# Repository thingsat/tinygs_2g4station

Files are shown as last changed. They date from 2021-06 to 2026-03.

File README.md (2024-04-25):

# TinyGS :: 2.4 GHz LoRa (low cost and low tech) ground station

Project to develop a ground station board that will receive messages from satellite on the 2.4GHz band. Satellite tracks are [Thingsat@STORK1](https://tinygs.com/satellite/ThingSat) and other cubeseat followed by the TinyGS community. This station is low cost (off the shelves boards and modules) and low tech (required only a solder iron).

This Git contains Hardware and software of a TinyGS 2.4 GHz LoRa ground station https://tinygs.com/.

TinyGS 2G4

## ESP32 Wroon 32U

The default MCU board is the [ESP32 Wroom 32U](https://www.espressif.com/sites/default/files/documentation/esp32-wroom-32d_esp32-wroom-32u_datasheet_en.pdf).

> Remark: The ESP32 Wroom 32D (on board PCB antenna) and The ESP32 Wroom 32U (UFL connector for an mandatory external antenna) can be used.

## SX1280 modules

For the long-range communication, we will use the Semtech SX1280, which is a low power 2.4 GHz LoRa RF Transceiver.

Several manufacturers provide RF modules integrating the SX1280 transceiver :
* [Lambda80 module](https://fr.farnell.com/rf-solutions/lambda80-24s/transceiver-2mbps-2-5ghz/dp/2988571)
* [EByte E28 module](https://www.amazon.com/Ebyte-%C3%89metteur-r%C3%A9cepteur-Bluetooth-E28-2G4M12S-%C3%A9metteur/dp/B07P2BZW5C)
* [SX1280PATR24 module](https://fr.aliexpress.com/item/1005001598235704.html) 
* [Miromico FMLR STM SX1280 module](https://miromico.ch/portfolio/fmlr-8x-x-stlx/?lang=en)
* [NiceRF LoRa1280 module](https://www.nicerf.com/products/detail/2-4ghz-lora-wireless-transceiver-module-lora1280-lora1281.html)
* [NiceRF LoRa1280-TCXO module](https://www.nicerf.com/products/detail/2-4ghz-range-measurement-wirelessly-long-distance-module-lora1280-tcxo.html)
* [NiceRF LoRa1280F27-TCXO module](https://www.nicerf.com/products/detail/500mw-2-4ghz-lora-wireless-transceiver-module-lora1280f27-tcxo.html)
* [Embit EMB-LR1280S](http://www.embit.eu/products/wireless-modules/emb-lr1280s/)

Project contains several PCBs and firmwares. 

##  Main Board

PCB are made to integrate up to 2 Mikrobus modules including SX1280 technology. Mikrobus board is an add-on board socket standard made by [mikroe](https://www.mikroe.com/mikrobus). This makes the ground station adjustable and modular.
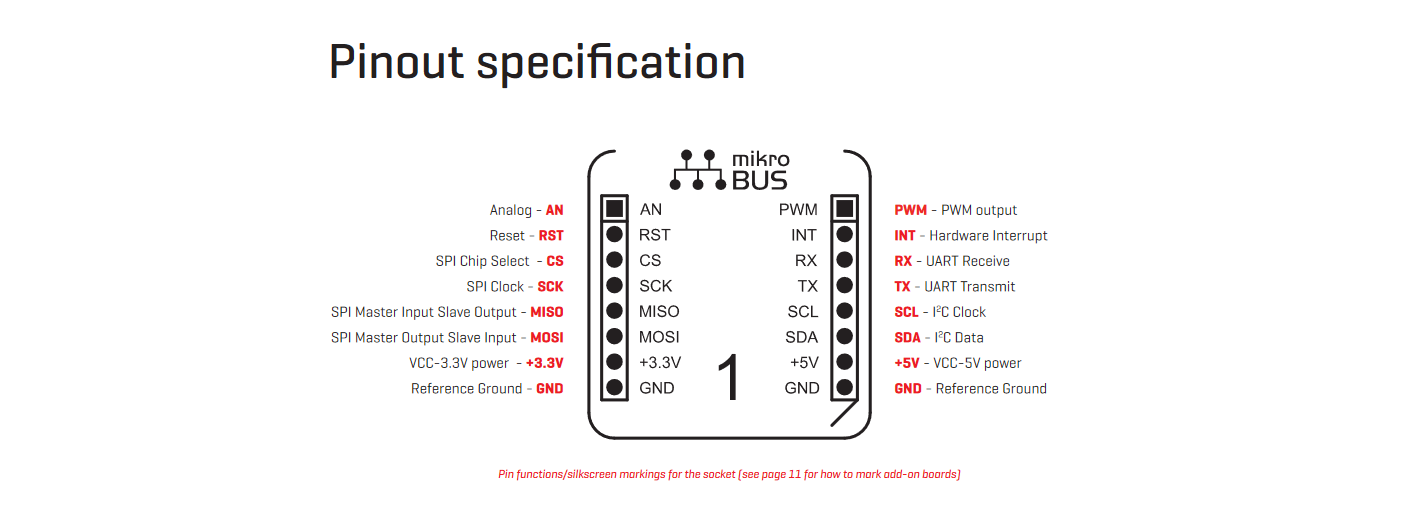
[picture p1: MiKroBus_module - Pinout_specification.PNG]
MiKroBus module
 

There are 2 different PCB version:
* Board_Tinysgs_2.4GHz_V1, which contains: ESP32 Wroom 32 + 2 Mikrobus modules + Grove connectors (RXTX,I2C,ANA)
* Board_Tinysgs_2.4GHz_V2, which contains: ESP32 Wroom 32 + 2 Mikrobus modules + Grove connectors (RXTX,I2C,ANA) + H-Bridges for driving stepper + Power supply

We made the board as modular as possible. It is possible to implement all modules as desired, as long as it respects the Mikrobus pin specification. Mikrobus module are connected by SPI, I2C, UART and more GPIO. They are both supplied by 3V and Mikrobus_1 is also supplied by 5V if desired. 2 SMA connector mount edge are available on board. Theyre a connected to a SMA male connector, which allows to plug any signal that we want through a SMA female connector.

Both Mikrobus boards are connected to the ESP 32 by SPI. They are using the same SPI bus (SPI_0).

PCB are made on [KiCad](https://www.kicad.org/), which is a free software for electronics circuit board design. PCBs has been manufactered by [JLCPCB](https://jlcpcb.com/).

##  Power

A [Power Bank NCR18650B Battery shield](https://www.amazon.com/Diymore-Lithium-Battery-Charging-Arduino/dp/B07SZKNST4) made for Arduino and ESP32 can be plugged under the board using the 4 screw holes.

##  Mikrobus adapters for SX1280 modules

The design of two Mikrobus adapters for SX1280 modules are currently provided by the project:

* [Lambda80 SX1280 module adapter](./Mikrobus_Board_Lambda80C/)
* [EByte E28 SX1280 module adapter](./Mikrobus_Board_EbyteE28/)
* [NiceRF_SX1280_TCXO SX1280 module adapter](./Board_Mikrobus_NiceRF_1280_TCXO/)

The pinouts of those adapters have some differences.

> Two versions of the E28 module exists: 12S & 20S

```
EByte28 module
AN  <-> Busy
INT <-> DIO1
PWM <-> DIO2

Lambda80C module
AN  <-> DIO1
INT <-> Busy
PWM <-> DIO2

NiceRF SX1280 TCXO module
AN  <-> ??
INT <-> ??
PWM <-> ??
```

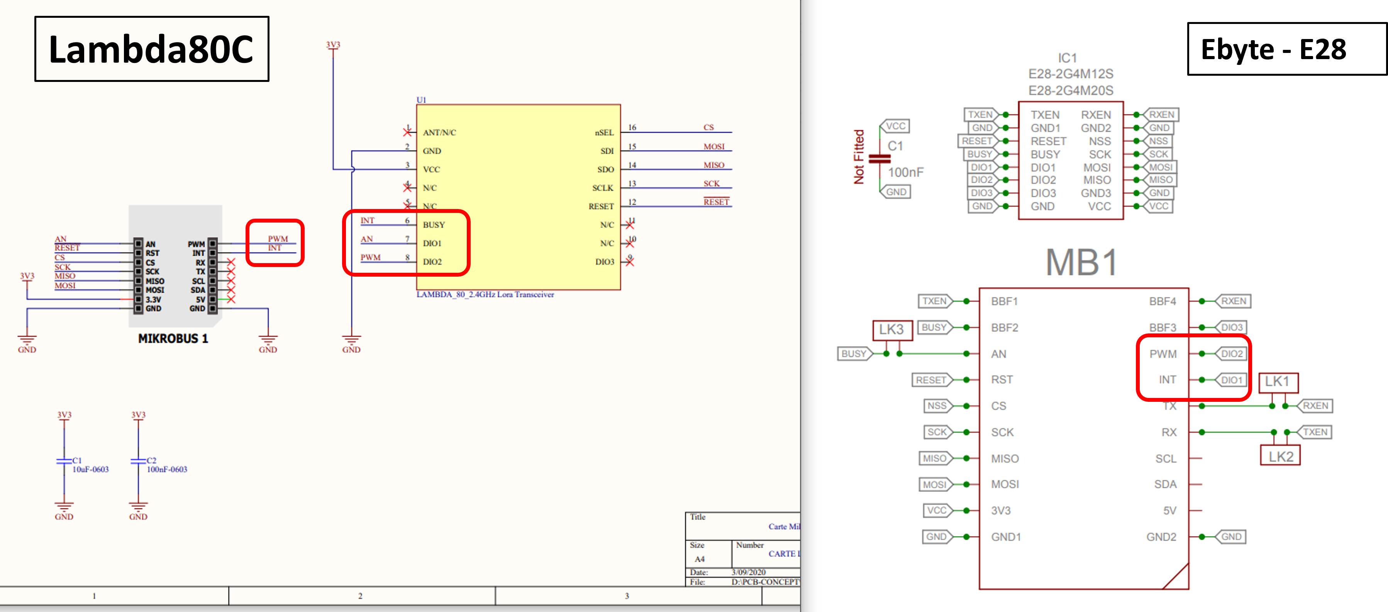
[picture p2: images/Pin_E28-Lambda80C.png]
pinouts differences


##  Other Mikrobus adapters for SX1280 modules

* [ ] [Geditech](https://www.geditech.fr/)'s LoRa SX1280 adapter
* [ ] [Stuart Robinson's (GW7HPW) Breadboard Friendly Board for NiceRF SX1280 Module](https://www.tindie.com/products/stuartsprojects/breadboard-friendly-board-for-nicrf-sx1280-module/)
* [ ] [Stuart Robinson's (GW7HPW) Breadboard Friendly Board for Ebyte E28 Module](https://www.tindie.com/products/stuartsprojects/breadboard-friendly-board-for-ebyte-e28-module/)

## Other Mikrobus modules (for the second Mikrobus slot)

Have a look into the [shop](https://www.mikroe.com/shop)

* [ ] [Geditech](https://www.geditech.fr/)'s LoRa Microchip RN2483 (for 433 MHz and 868 MHz ISM bands)

## Firmware

Firmware are into [./Firmware](./Firmware).

## Off-the-shelves gateways for LoRa 2.4 GHz

Those gateways had 3 LoRa® 2.4GHz channels for Rx and 1 LoRa® 2.4GHz channels for Tx.

* [Multitech MTCDT + MCard MTAC-LORA-2G4-3](https://www.multitech.net/developer/software/lora/mtac-lora-2g4-3/)
* [SX1280Z3DSFGW1 LoRa® 2.4GHz 3 Channels Single SF Reference Design](https://fr.semtech.com/products/wireless-rf/lora-24ghz/sx1280zxxxxgw1) (included a removable mPCIe card).
* [Embit EMB-FEM2GW-O-2G4](http://www.embit.eu/products/gateways-2/emb-fem2gw-o-2g4/) (included a removable mPCIe card EMB-LR1280-mPCIe-4x).

## References

* [ESP32-DevKitC V4 Getting Started Guide](https://docs.espressif.com/projects/esp-idf/en/latest/esp32/hw-reference/esp32/get-started-devkitc.html)
* [ESP32 Wroom 32 D/U Datasheet](https://www.espressif.com/sites/default/files/documentation/esp32-wroom-32d_esp32-wroom-32u_datasheet_en.pdf)

## Buy

### ESP32 Wroon 32U

* [ESP32-DevKitC-32U @ Aliexpress](https://fr.aliexpress.com/wholesale?SearchText=ESP32+Wroom+32U)
* [ESP32-DevKitC-32U @ Mouser](https://www.mouser.fr/ProductDetail/Espressif-Systems/ESP32-DevKitC-32U?qs=%252BEew9%252B0nqrCEVvpkdH%2FG5Q==)
* [ESP32-DevKit-LiPo @ Olimex](https://www.olimex.com/Products/IoT/ESP32/ESP32-DevKit-LiPo/open-source-hardware)

> **Important: ESP32 Wroon 32U had 38 pins and an UFL connector for an external (high gain and directive) antenna. ESP32 Wroon 32D had 38 pins and a PCB antenna. Choose ESP32 Wroon 32U for a better link margin.**

### SX1280 modules

* [LAMBDA80C-24D @ Farnell](https://fr.farnell.com/rf-solutions/lambda80c-24d/transceiver-2mbps-2-5ghz/dp/2988574?st=lambda80) (UFL connector + EM shield)
* [LAMBDA80C-24S @ Mouser](https://www.mouser.fr/ProductDetail/RF-Solutions/LAMBDA80C-24S?qs=17u8i%2FzlE89dhjIrlJ9FHg%3D%3D) (UFL connector + EM shield)
* [EByte E28-2G4M20S @ Aliexpress](https://fr.aliexpress.com/item/1005001812057589.html) (UFL connector + EM shield)

### PCB

* [Wuerth Elektronik](https://www.we-online.com/web/fr/wuerth_elektronik/start.php) 
* [JLCPCB](https://jlcpcb.com/)

### Headers and connectors
* [20-pin stackable headers (x2)](https://www.mouser.fr/ProductDetail/SparkFun/PRT-14311?qs=sGAEpiMZZMv0NwlthflBiwoz7B0w9MUDoIB50flBSMs%3D) for ESP32 : should be resized to 19 pins.
* [8-pin stackable headers (x2)](https://www.mouser.fr/ProductDetail/SparkFun/PRT-10007?qs=sGAEpiMZZMvShe%252BZiYheitG2EllKzxS98FBwaVjriqQ%3D) for Mikrobus modules.
* [Grove connectors (x3 but optional)](https://www.mouser.fr/ProductDetail/Seeed-Studio/110990030?qs=1%252B9yuXKSi8Dw9fpnq%252BdNzQ%3D%3D).

### Power (Optional)
* [Diymore 2x18650 Battery Pack @ Aliexpress](https://fr.aliexpress.com/item/33016661427.html)
* [DFRobot Solar Power Manager 5V](https://www.dfrobot.com/product-1712.html)
* [DFRobot Solar Power Manager Micro](https://www.dfrobot.com/product-1781.html)
* [Adafruit Universal USB / DC / Solar Lithium Ion/Polymer charger - bq24074](https://learn.adafruit.com/adafruit-bq24074-universal-usb-dc-solar-charger-breakout/design-notes)

### Power Profiling
* [Nordic Power Profiler Kit II](https://github.com/CampusIoT/tutorial/tree/master/nrf-ppk2#readme)
> Plug the PPK2 power source (`VOUT`+`GND`) on `3V3`+`GND` pin (double-row header and Grove connectors) and DO NOT plug the ESP32 throught the mini-USB connector.

### Debbuging
* [ ] [Click Analyzer](https://www.mikroe.com/click-analyzer)

## 2.4 GHz antennas
* [SuperAntennaz](https://wiki.satnogs.org/SuperAntennaz)
* [DIY Quadrifilar Helix Antenna for 2450 MHz](https://www.thingiverse.com/thing:634205)
* [Sirio SDC-2.4-15](https://www.sirioantenne.it/en/products/wlan/sdc-2-4-15): Directional, Linear Vertical or Horizontal Polarization, 12.9 dBd – 15 dBi.
  
## Licenses

For PCB designs, the license is [Attribution-NonCommercial-ShareAlike 4.0 International (CC BY-NC-SA 4.0)](https://creativecommons.org/licenses/by-nc-sa/4.0/).

For Software, check the license into each directory.

## Todolist

* [x] PCB for ESP32 Wroom 32 (38 pins) + 2 Mikrobus modules + 3 groves connectors (RXTX,I2C,ANA)
* [ ] PCB for ESP32 Wroom 32 (38 pins) + 2 Mikrobus modules + 3 groves connectors (RXTX,I2C,ANA) + H-Bridges for driving stepper + Power supply
* [x] Mikrobus adapter for Lambda80 SX1280 module
* [x] Mikrobus adapter for EByte E28 SX1280 module
* [ ] Mikrobus adapter for [SX1280PATR24 module](https://fr.aliexpress.com/item/1005001598235704.html) 
* [ ] Mikrobus adapter for [Miromico FMLR STM SX1280 module](https://miromico.ch/portfolio/fmlr-8x-x-stlx/?lang=en)
* [ ] Mikrobus adapter for [NiceRF SX1280 module](https://stuartsprojects.github.io/2019/10/07/2-4ghz-nicerf-sx1280-lora-balloon-tracker-85km-achieved.html)
* [ ] Mikrobus adapter for [Microchip RN2483 module](https://www.microchip.com/en-us/product/RN2483)
* [ ] Mikrobus adapter for [RF Solutions RF-LORA-868-SO module](https://fr.rs-online.com/web/p/lpwan/9033059)
* [ ] Mikrobus adapter for [Abeeway-Murata Geolocation Module](https://docs.abeeway.com/thingpark-location/B-Feature-Topics/GeolocModule_C/)
* [ ] Mikrobus protoshield
* [x] [Arduino sketches](./Firmware/Arduino/SX1280) for ESP32 Wroom 32 + E28 Mikrobus module
* [x] [Arduino sketches](./Firmware/Arduino/SX1280) for ESP32 Wroom 32 + Lambda80 Mikrobus module
* [ ] [Arduino sketches](./Firmware/Arduino/SX1280) for Wio Terminal + Lambda80 Mikrobus module
* [ ] Move UART Grove connector for using Grove cable with ESP32-WROOM-32D (PCB antenna)
* [ ] TinyGS firmware for ESP32 Wroom 32 + E28 Mikrobus module
* [ ] TinyGS firmware for ESP32 Wroom 32 + Lambda80 Mikrobus module
* [ ] TinyGS firmware for ESP32 Wroom 32 + [Miromico FMLR STM SX1280 module](https://miromico.ch/portfolio/fmlr-8x-x-stlx/?lang=en)
* [ ] TinyGS firmware for ESP32 Wroom 32 + [LR1120 Dev Kit module](https://fr.semtech.com/products/wireless-rf/lora-edge/lr1120dvk1tbks) for such modulations and bands : LoRa SubGHz, LoRa 2.4GHz, LR-FHSS, S-Band (1.9-2.1GHz)
* [ ] TinyGS firmware for [Wio Terminal](https://wiki.seeedstudio.com/Wio-Terminal-Getting-Started/) + Lambda80 Mikrobus module
* [ ] Power consumption study with [X-NUCLEO-LPM01A](https://www.st.com/en/evaluation-tools/x-nucleo-lpm01a.html)
* [ ] RIOTOS firmware for ESP32 Wroom 32 + Lambda80 module (cubesat emulator)
* [ ] Test the [Geditech](https://www.geditech.fr/)'s LoRa Microchip RN2483 (for 433 MHz and 868 MHz ISM bands) on second slot.
* [ ] Add slots for I2C and UART grove connectors into the two Mikrobus slots (can be used when the Mikrobus slot is not used)
* [ ] Add slot for female header in order to plug a low-cost SDCard SPI breakout (useful for data logging)
* [ ] Add slot for female/male header in order to plug a low-cost DS1307/DS3231 breakout (useful for timestamping data log entries)
* [ ] Add extra slot for power sources (3V3, VCC)
* [ ] Add white label for DevEUI and serial number on silkscreen layer
* [ ] Add pin for IRQ on [GNSS PPS](https://en.wikipedia.org/wiki/Pulse-per-second_signal)
* [ ] Design Fritzing part for the station
* [x] add licenses
* [ ] review PCB designs according the [Mikrobus specifications v2.0](https://download.mikroe.com/documents/standards/mikrobus/mikrobus-standard-specification-v200.pdf)
* [ ] add L9616 CAN driver footprint ([see](https://copperhilltech.com/blog/can-bus-development-with-esp32wroom32-development-board/)) connected to `CAN_TXD = ESP32 – IO25` and `CAN_RXD = ESP32 – IO26`

## Media

Here the picture of the board_V1, with or without modules. On last picture, a GPS, a magnetometer and a joystick are connected by grove connection.

TinyGS 2G4
Mounted PCB with Grove boards ([Grove Thumb Joystick](https://wiki.seeedstudio.com/Grove-Thumb_Joystick/), [Grove  LSM6DS3 Accelerometer Gyroscope](https://wiki.seeedstudio.com/Grove-6-Axis_AccelerometerAndGyroscope/), [Grove GPS](https://wiki.seeedstudio.com/Grove-GPS/)) and Lamdba80 and E28 module.
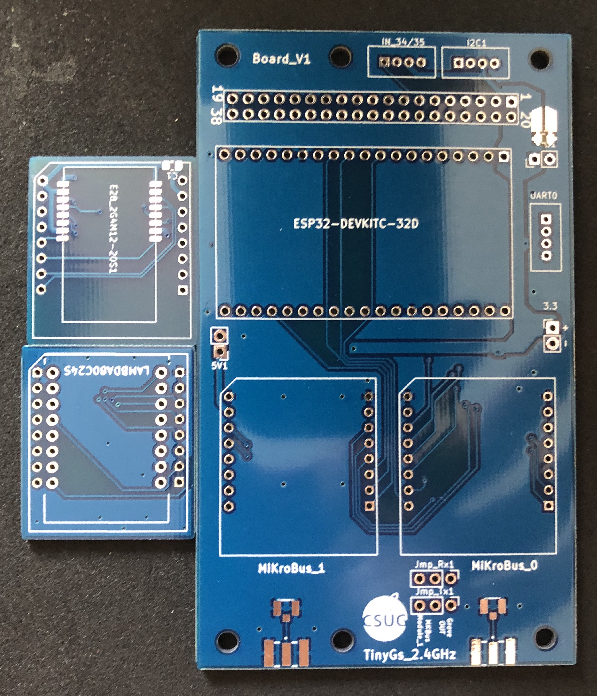
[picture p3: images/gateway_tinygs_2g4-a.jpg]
TinyGS 2G4

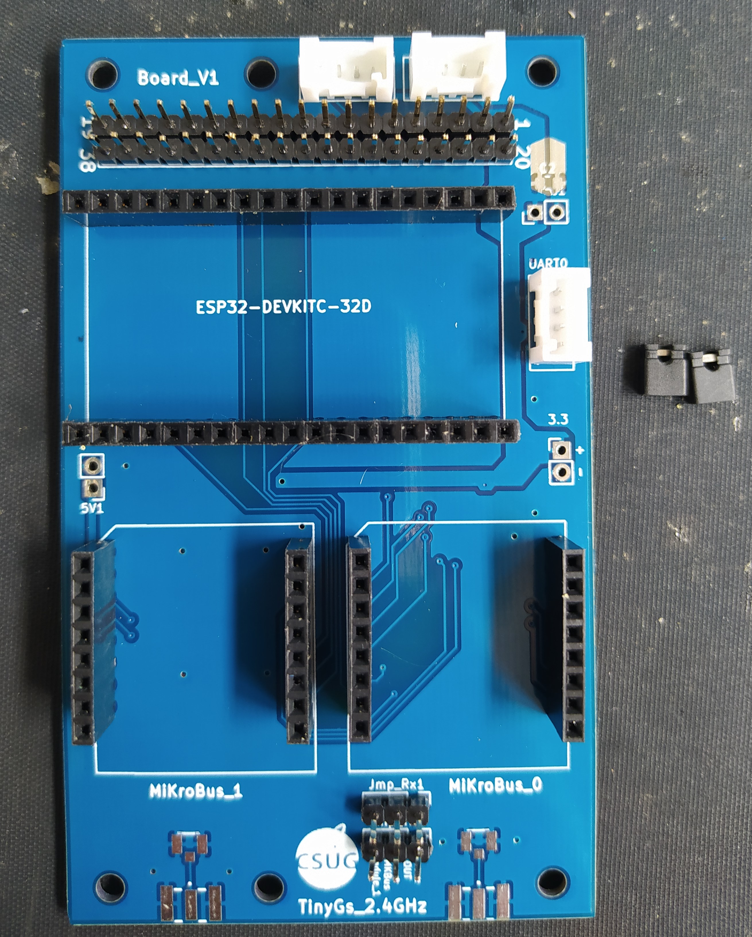
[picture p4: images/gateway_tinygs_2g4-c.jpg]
TinyGS 2G4

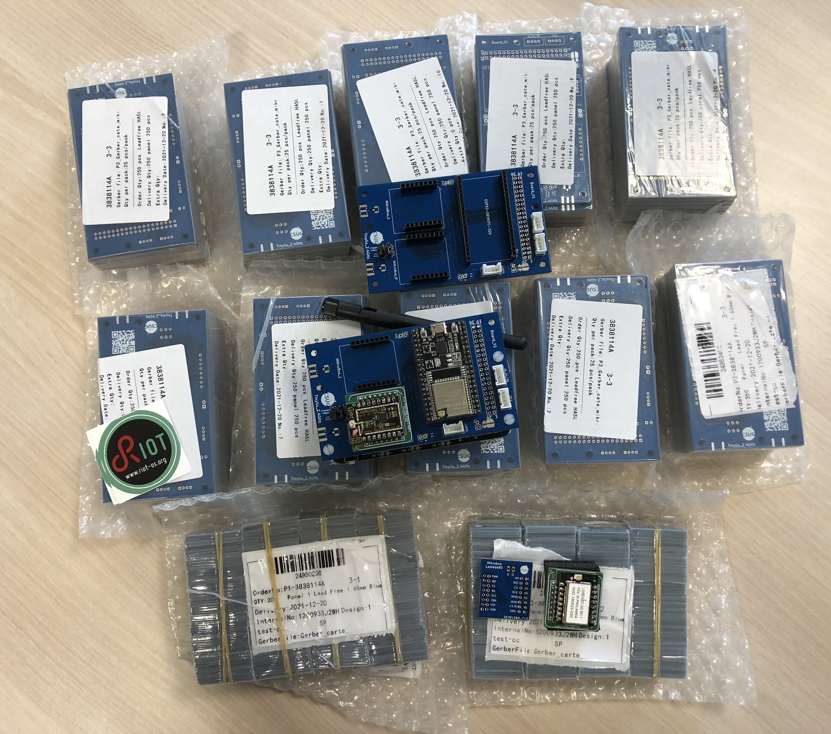
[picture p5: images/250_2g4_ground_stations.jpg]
250 PCB for TinyGS 2G4

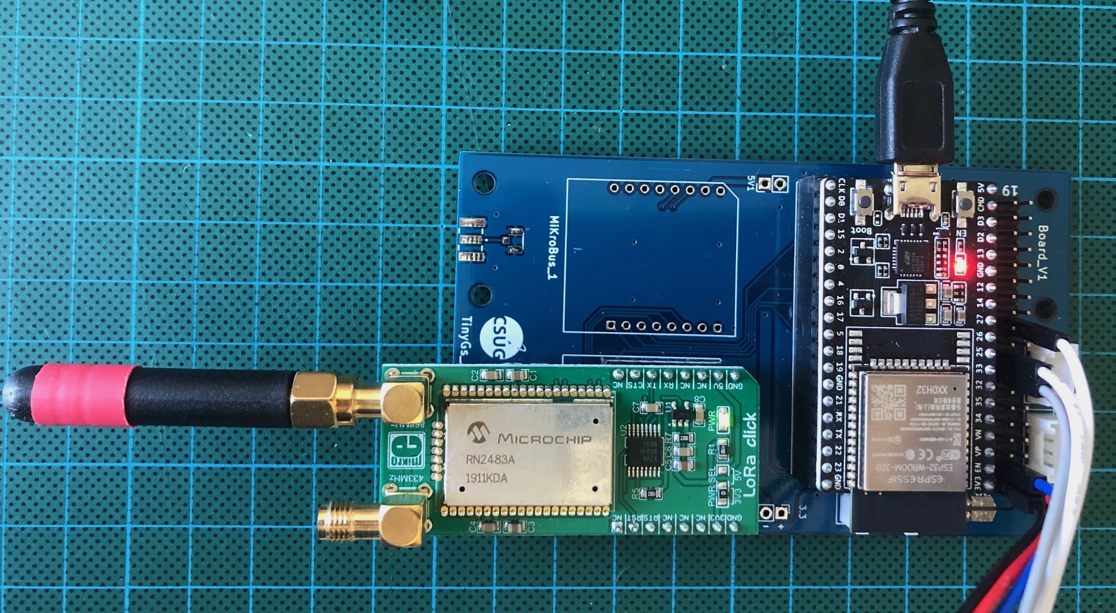
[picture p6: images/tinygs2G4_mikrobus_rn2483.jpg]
TinyGS 2G4 + RN2483 Mikrobus module (eu433,eu868)

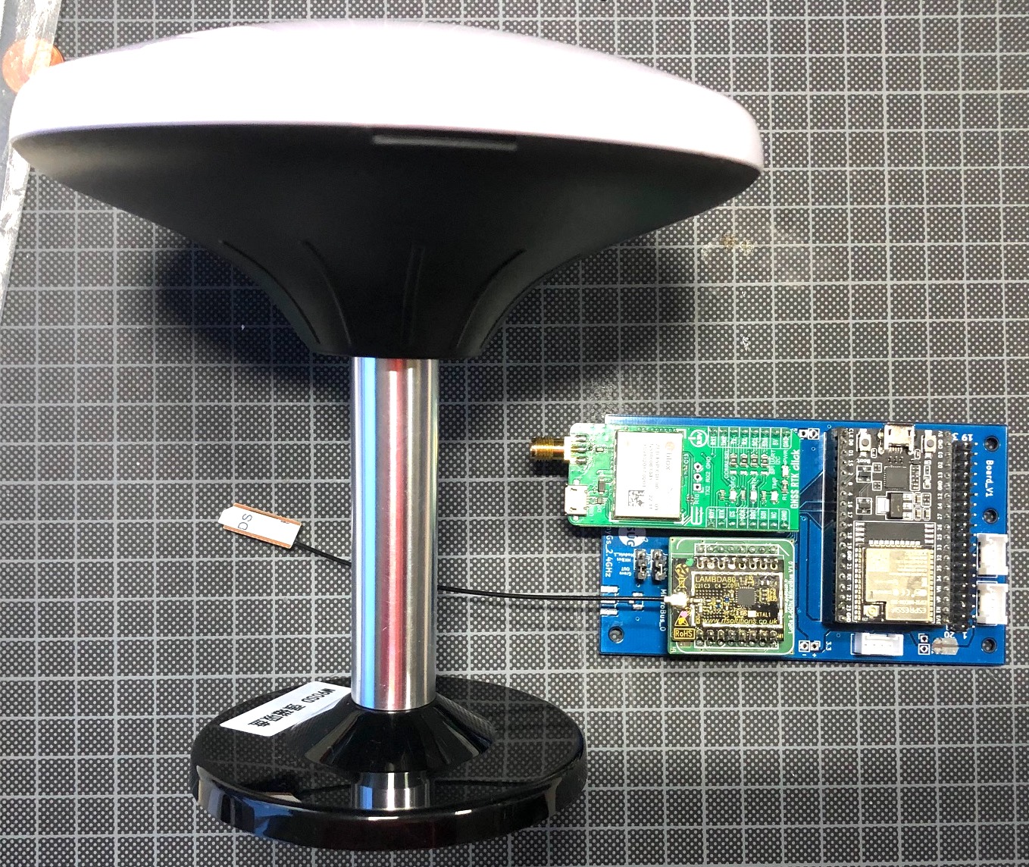
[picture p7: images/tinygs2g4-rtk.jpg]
TinyGS 2G4 + RTK

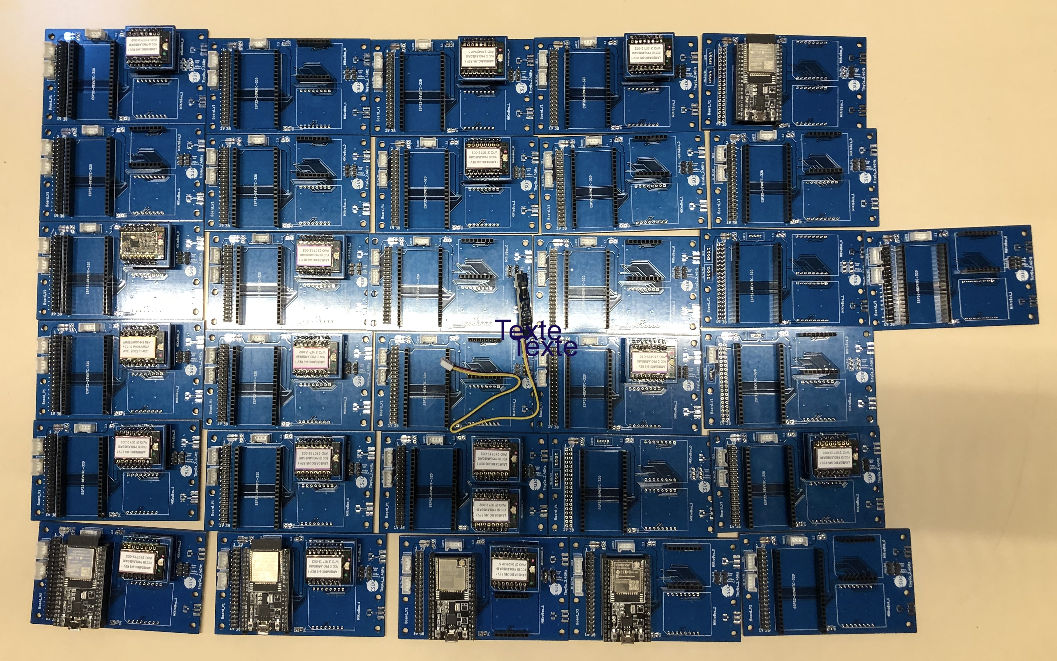
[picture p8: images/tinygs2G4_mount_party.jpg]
TinyGS 2G4 Mount Party @ IUT1 Grenoble Dept GEII


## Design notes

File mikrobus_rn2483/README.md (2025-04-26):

# Mikrobus adapter for Microchip RN2483 module

The Microchip RN2483 module is a LoRa/LoRaWAN modem on 433 MHz and 868 MHz bands.

## See
* https://www.mikroe.com/lr-click
* https://github.com/KiCad/RF_Modules.pretty
* https://github.com/SodaqMoja/Sodaq_RN2483
* https://github.com/CampusIoT/tutorial/blob/master/rn2483/README.md

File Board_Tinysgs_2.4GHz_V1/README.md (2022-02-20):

# Main Board for TinyGS 2.4GHz Station

This board is the firts version of the 2.4GHz gateway for [TinyGS](https://tinygs.com/).

Contain Schematic and PCB file for ESP32 Vroom + 2 Mikrobus modules + 2 groves connectors (RXTX,I2C).

This Board is designed to support a ESP32 devkitC-V4 and 2 MiKroBus modules. This board is the firts version of the 2.4GHz tinygs ground station gateway and named Board_V1

The purpose of this board is to control mikrobus modules including SX1280 technology that will transmit and receive messages on a 2.4GHz radio frequency. Each module are connected to a ESP32 which will be connected to the wifi.

Mikrobus board is an add-on board socket standard made by [mikroe](https://www.mikroe.com/mikrobus)

Connection between ESP32 - ESP32-DevKitC V4 and Mikrobus modules

MiKroBus 0:
	 				 
	SPI_0:
	CLK 	IO18
	MISO	IO19
	MOSI	IO23
	NSS(CS)	IO05
	
	UART_0	:
	Tx	IO01
	Rx	IO03
	
	I2C:
	SDA	IO21
	SCL	IO22
	
	AN_0	IO33
	RESET_0 IO32
	PWM_0	IO25
	INT_0	IO26

MiKroBus 1: 				 
	
	SPI_0
	CLK 	IO18
	MISO	IO19
	MOSI	IO23
	NSS 	IO15
	
	UART_2
	Tx	IO17
	Rx	IO16
	
	I2C:
	SDA	IO21
	SCL	IO22
	
	AN_1	IO27
	RESET_1 IO14
	PWM_1	IO04
	INT_1	IO13

Grove connector available on board :

	I2C:			UART_2(Rx/Tx):		GPIO(INPUT Only):
	SDA   IO21		Tx	IO17		IO34
	SCL   IO22		Rx	IO16		IO35

UART_2 can be connected to module MiKroBus 2 or to grove connector. A jumper need to be plug to choose beetween grove output or the mikrobus module.

Two UFL connected to a SMA mount edge connector are available to plug an antenna. They are disconnected from the rest of the board, which allows to connect the module that you want to the antenna, with a SMA -UFL connector.

A powerbank can be plug under the board to supply the 3V. The [powerbank](https://www.amazon.com/Diymore-Lithium-Battery-Charging-Arduino/dp/B07SZKNST4) is design for ESP32 and is purchasable on amazon. 
5V is only available on the Mikrobus 1 module. 

Careful:
* UART0 is used for flashing and debuging. Be very careful to its use.
* GPIO grove connector are INPUT only, ESP32wroom cannot write on this connection.
* Both Chip selec (NSS) for the SPI communication are Pulled HIGH (IO05 & IO15).
* No 5V on Mikrobus 0. 

## Library and footprint

Lib & empreinte folder contains all necessary symbol and footprint for the project:
* ESP32 symbol and footprint. Footprint has been changed to match with our ESP32-devkitC-V4
* Mikrobus (mikroe-2439) symbol and footprint
* Grove connector for I2C and RxTx connection
* SMA and UFL connector

## Files
* .pro: File containing the parameters of the project.
* .sch: Schema files.
* .kicad_pcb: Printed circuit board files.
* sym-info-cache: Library list file (symbol library table): declaration of component symbol libraries available for the schema editor.
* fp-lib-table: Library list file (footprint library table): declaration of component footprint libraries available for the PCB editor.

## Rendered

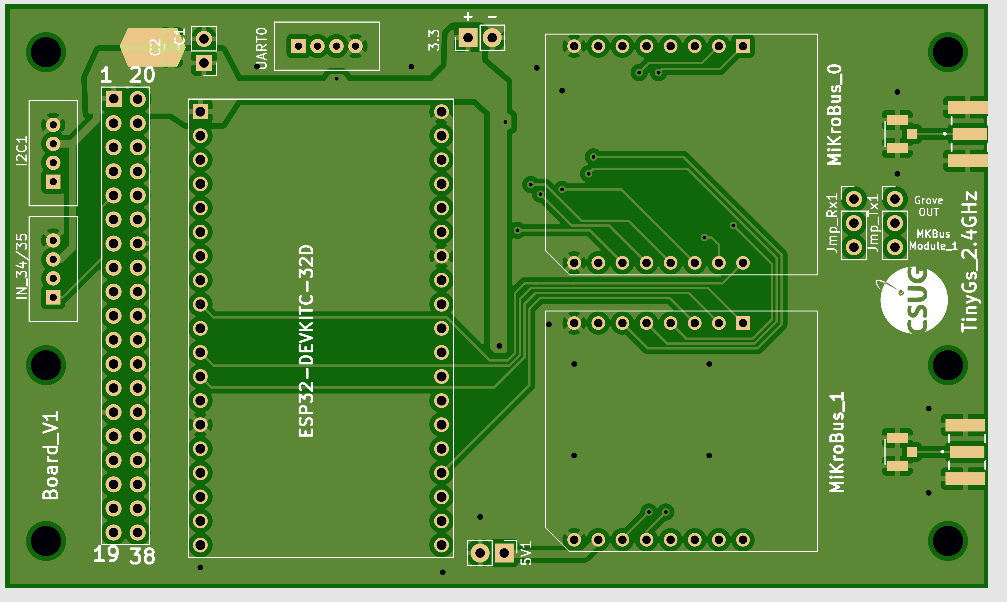
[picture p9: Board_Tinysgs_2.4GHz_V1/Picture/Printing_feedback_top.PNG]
Printing_feedback_top
 
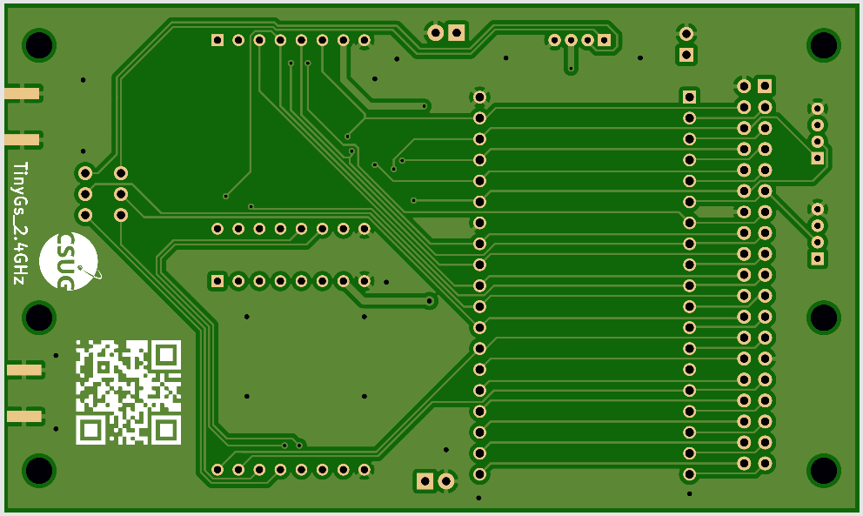
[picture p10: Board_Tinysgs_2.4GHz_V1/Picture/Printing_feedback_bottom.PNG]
Printing_feedback_bellow


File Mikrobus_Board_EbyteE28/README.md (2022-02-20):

# Mikrobus Adapter for Ebyte E28 SX1280 Module

This is a board to support a Ebyte E28 2.4GHz LORA transceiver RF module, adapted to Mikrobus standard pinout specification. This board will allow you to use your Ebyte E28-2G4M module with a standard 0.1” matrix breadboard or a Mikrobus Standard.

The Ebyte E28-2G4M is a RF transceiver module using the Semtech SX1280 LoRa technology, operate in 2.400 ~ 2.500GHz with ultra-low power consumption. More information available on [Ebyte site](https://www.ebyte.com/en/product-view-news.html?id=286). 

This board can support E28_2G4M12S and E28_2G4M20S. This Ebyte E28 Board is inspired by the [Breadboard Friendly Ebyte E28 Board](https://github.com/StuartsProjects/Devices/tree/master/Breadboard%20Friendly%20EbyteE28%20Board) made by StuartsProjects.

Ebyte E28 module usable: [Ebyte E28-2G4M12S](https://www.amazon.fr/Ebyte-%C3%89metteur-r%C3%A9cepteur-Bluetooth-E28-2G4M12S-%C3%A9metteur/dp/B07P2BZW5C) / [Ebyte E28-2G4M20S](https://www.amazon.fr/EBYTE-E28-2G4M20S-SX1280-%C3%89metteur-R%C3%A9cepteur/dp/B07R77CKFK). They are the same module, exept that the E28-2G4M20S as 2 more Pins (14 pin for 12S and 16 pin for 20S).These extra pins are for Rx/Tx connection for PA and LNA control.

Here the connection between the Mikrobus standard pin and the E28 module pin

	AN	<->	Busy
	RST	<->	NRESET
	CS	<->	NSS_CTS
	SCK	<->	SCK_RTS
	MISO	<->	MISO_TX
	MOSI	<->	MOSI_RX
	PWM	<->	DIO2
	INT	<->	DIO1
	
	for M20S
	Rx	<->	TX_EN
	Tx	<->	RX_EN

Ebyte E28 is supplied with 3.3V, by the +3.3V Mikrobus pin.

The Ebyte E28 module has a PCB antenna, so no external antenna is needed, but the here also a SMA connector to use a external antenna.

## Kicad Project
The project was made on Kikad, which is a free software for electronics circuit board design, developed by IUT of Grenoble.

For the mikrobus lib and footprint, I use the [MIKROE-924](https://componentsearchengine.com/part-view/MIKROE-924/MIKROELEKTRONIKA) model available on [component search engine](https://componentsearchengine.com/).
For the E28 schematic and footprint, I found nothing on internet so I made my own. 

All the schematic and footprint are in the "Lib & Fp" folder. For the Mikrobus lib, you have to choose the KiCad folder.

## TODO

* [ ] Move module in order to place the PCB antenna outside of the adapter.

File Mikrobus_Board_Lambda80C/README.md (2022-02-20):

# Mikrobus Adapter for Lambda80-24S SX1280 Module

This is a board to support a lambda80C 2.4GHz LORA transceiver RF module, adapted to Mikrobus standard pinout specification.

Lambda Module used: [Lambda80-24S](https://fr.farnell.com/rf-solutions/lambda80-24s/transceiver-2mbps-2-5ghz/dp/2988571). The LAMBDA80 is a 2.4GHz LoRa transceiver using the Semtech SX1280 technology, providing ultra-long range, spread spectrum communication and high interference immunity within minimal current. For more information on [SX1280](https://github.com/thingsat/tinygs_2g4station/blob/main/Datasheet_SEMTECH_SX1280.PDF).

Some Specification:
* Transmit power +12.5 dBm
* High sensitivity: down to -132 dBm
* RF Data Rate: FSK upto 2.02Mbps - LoRa upto 476bps

Programing of the module is via SPI interface. This module has as pin BUSY, RESET, SPI, 3 DIO (Digital I/O software configured) and a Antenna connection “C” Versions. Antenna  is connectable with a connector UFL female.

Here the connection between the Mikrobus standard pin and the Lambda80 module pin

	AN	<->	DIO1
	RST	<->	RESET
	CS	<->	NSEL
	SCK	<->	SCLK
	MISO	<->	SDO
	MOSI	<->	SDI
	PWM	<->	DIO2
	INT	<->	BUSY

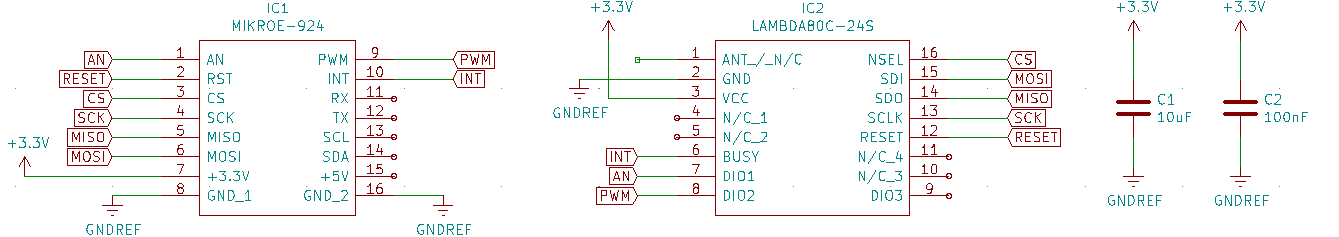
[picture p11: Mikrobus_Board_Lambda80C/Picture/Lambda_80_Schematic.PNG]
Lambda_80_Schematic


Lambda80 is supplied with 3.3V, by the +3.3V Mikrobus pin.

The Ebyte E28 module has no PCB antenna, so a external antenna is needed. A UFL male connector is available on the module to plug a external antenna with a UFL female connector.

### Kicad Project
The project was made on Kikad, which is a free software for electronics circuit board design, developed by IUT of Grenoble.

For the mikrobus lib and footprint, I use the [MIKROE-924](https://componentsearchengine.com/part-view/MIKROE-924/MIKROELEKTRONIKA) model available on [component search engine](https://componentsearchengine.com/).
For the Lambda80, I use the [Lambda80](https://componentsearchengine.com/part-view/LAMBDA80-24S/RF%20SOLUTIONS) model.

All the schematic and footprint are in the "Lib & Fp" folder. For the Mikrobus and Lambda80 lib, you have to choose the KiCad folder when adding the lib to the project.

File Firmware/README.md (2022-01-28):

# TinyGS 2G4 station :: Firmware

You will find here all the firmware that you need for your 2.4GHz ground station using SX128x module.

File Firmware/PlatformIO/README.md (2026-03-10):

# PlatformIO

TODO

Board is [esp32dev](https://docs.platformio.org/en/latest/boards/espressif32/esp32dev.html)

https://docs.platformio.org/en/stable/tutorials/espressif32/arduino_debugging_unit_testing.html

https://github.com/jandelgado/jled-esp-idf-platformio-example

## Framework
* https://docs.platformio.org/en/latest/frameworks/espidf.html#framework-espidf
* https://docs.platformio.org/en/latest/frameworks/arduino.html#framework-arduino

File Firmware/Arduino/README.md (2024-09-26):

# TinyGS 2G4 :: Firmware :: Arduino

### Toolchain and SX128x Libraries

Add the Espressif toolchain `https://dl.espressif.com/dl/package_esp32_index.json` into `Preferences > URL of Board manager` 

Select the ESP32 board into `Tools > Board type > ESP32 Arduino > ESP32 Dev Module`

Download the lib `https://codeload.github.com/StuartsProjects/SX12XX-LoRa/zip/refs/heads/master`

Install the lib with `Sketch > Include Lib > Add Zip Lib`

Set the serial console to `115200 8N1`.

## Examples

### Wifi

* In `Examples` > `Wifi > WifiScan`
* In `Examples` > `ESP32 > GetMacAddress`
* In `Examples` > `ESP32 > GetChipID`

### LoRa SX1280

* [SX1280](./SX1280) for StuartsProjects - SX12XX

### Networks

* [MQTT](./MQTT) : simple MQTT publisher. Scan of Wifi SSID for searching the Wifi hotspot
* [UDP Dataframe (Semtech UDP Packet Forwarder)](https://github.com/dragino/Arduino-Profile-Examples/tree/master/libraries/Dragino/examples/LoRa/LoRaWAN/LoRaWAN_packet_forwarder)
* [OpenMQTTGateway](https://docs.openmqttgateway.com/)

### Sensors

* [23_GPS_Tracker_Transmitter](./23_GPS_Tracker_Transmitter) with [Grove GPS](https://wiki.seeedstudio.com/Grove-GPS/)
* [Analog_Input_Joystick](./Analog_Input_Joystick) : with [Grove Thumb Joystick](https://wiki.seeedstudio.com/Grove-Thumb_Joystick/)
* [TinyGPSPlus_FullExample](./TinyGPSPlus_FullExample)
* [Grove_LSM6DS3_Accelerometer_Gyroscope](./Grove_LSM6DS3_Accelerometer_Gyroscope) with [Grove  LSM6DS3 Accelerometer Gyroscope](https://wiki.seeedstudio.com/Grove-6-Axis_AccelerometerAndGyroscope/)

Seeedstudio proposes other boards with [various accelerometers](https://wiki.seeedstudio.com/Sensor_accelerometer/).

### Misc

* [TinyGPSPlus_SatelliteTracker](./TinyGPSPlus_SatelliteTracker)
* [ArduinoP13 TLE](https://github.com/TNeutron/ArduinoP13)
* [JSON](https://arduinojson.org/)
* [Sat Tracker](https://github.com/alexchang0229/SatelliteTracker)
* In `Examples`, `TFLite Micro > hello_world`

## Arduino external libraries

### tinyGS RadioLib
The firmware [RadioLib](https://github.com/thingsat/tinygs_2g4station/tree/main/Firmware/Exemple/Transceiver_modules-RadioLib) is provided by the [tinyGS](https://github.com/G4lile0/tinyGS) community. TinyGS is an open network of Ground Stations distributed around the world to receive and operate LoRa satellites, using cheap and versatile modules. [RadioLib by TinyGS](https://github.com/G4lile0/tinyGS/tree/master/lib/RadioLib) allows its users to integrate all sorts of different wireless communication modules, protocols and even digital modes into a single consistent system. This Lib allow to use a large number of different transceiver modules, protocols and platforms on Arduino IDE.

### StuartsProjects - SX12XX 	
The firmware [SX12XX](https://github.com/thingsat/tinygs_2g4station/tree/main/Firmware/Exemple/Transceiver_modules-SX12XX) is provided by [StuartsProjects](https://github.com/StuartsProjects). StuartsProjects is a independent user which for the last few years has been mostly to do with exploring the capabilities and applications for devices using Semtech�s LoRa�. Thanks to him, he publish all his work ant test on his GitHub page, with some nice description and explanation. 

StuartsProjects made a lib for Semtechs SX12XX LoRa device.[SX12XX-LoRa](https://github.com/StuartsProjects/SX12XX-LoRa). His library supports the SX126x, SX127x and SX128x Semtech LoRa devices. Therefore, the library does not support LoRa modules with a UART based interface such as those from Ebyte and Microchip. There are examples for sending\receiving a simple character buffer ("Hello World") using the SX1280 LoRa module with a ESP32.

StuartsProjects publish a ranging test unsing the G-NiceRF LoRa1280 devices: [SX1280_Testing](https://github.com/StuartsProjects/SX1280_Testing). He uses the SX1280 ranging mode that can measure distance by recording the time of flight of a special packet exchange between two SX1280s. However, the code seems not be published.

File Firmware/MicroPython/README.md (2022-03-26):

# TinyGS ESP32 and MicroPython

## Installation

Download and flash the latest firmware of micropython for ESP32 boards
* http://micropython.org/download/
* https://micropython.org/download/esp32

Download the esptool.py [here](https://github.com/espressif/esptool).

```bash
mkdir ~/github/espressif
cd ~/github/espressif
git clone https://github.com/espressif/esptool
```

```bash
ESPTOOL=~/github/espressif/esptool/esptool.py
PORT=/dev/tty.usbserial-0001
FIRMWARE=~/Downloads/esp32-20220117-v1.18.bin
$ESPTOOL --chip esp32 --port $PORT erase_flash
```

```
esptool.py v2.4.0
Connecting........_____....._____..
Chip is ESP32D0WDQ6 (revision 1)
Features: WiFi, BT, Dual Core, 240MHz, VRef calibration in efuse
MAC: 58:bf:25:92:c7:3c
Uploading stub...
Running stub...
Stub running...
Erasing flash (this may take a while)...
Chip erase completed successfully in 13.2s
Hard resetting via RTS pin...
```

```bash
$ESPTOOL --chip esp32 --port $PORT --baud 460800 write_flash -z 0x1000 $FIRMWARE
```

```
esptool.py v2.4.0
Connecting.....
Chip is ESP32D0WDQ6 (revision 1)
Features: WiFi, BT, Dual Core, 240MHz, VRef calibration in efuse
MAC: 58:bf:25:92:c7:3c
Uploading stub...
Running stub...
Stub running...
Changing baud rate to 460800
Changed.
Configuring flash size...
Auto-detected Flash size: 4MB
Compressed 1555136 bytes to 1022998...
Wrote 1555136 bytes (1022998 compressed) at 0x00001000 in 24.9 seconds (effective 500.2 kbit/s)...
Hash of data verified.

Leaving...
Hard resetting via RTS pin...
```

## Basic tests

```bash
minicom -D $PORT
```

```
MicroPython v1.18 on 2022-01-17; ESP32 module with ESP32
Type "help()" for more information.
>>> help()
Welcome to MicroPython on the ESP32!

For generic online docs please visit http://docs.micropython.org/

For access to the hardware use the 'machine' module:

import machine
pin12 = machine.Pin(12, machine.Pin.OUT)
pin12.value(1)                                                                 
pin13 = machine.Pin(13, machine.Pin.IN, machine.Pin.PULL_UP)                   
print(pin13.value())                                                           
i2c = machine.I2C(scl=machine.Pin(21), sda=machine.Pin(22))                    
i2c.scan()                                                                     
i2c.writeto(addr, b'1234')                                                     
i2c.readfrom(addr, 4)                                                          
                                                                                
Basic WiFi configuration:                                                      
                                                                                
import network                                                                 
sta_if = network.WLAN(network.STA_IF); sta_if.active(True)                     
sta_if.scan()                             # Scan for available access points    
sta_if.connect("<AP_name>", "<password>") # Connect to an AP                   
sta_if.isconnected()                      # Check for successful connection     
                                                                                
Control commands:                                                              
  CTRL-A        -- on a blank line, enter raw REPL mode                        
  CTRL-B        -- on a blank line, enter normal REPL mode                     
  CTRL-C        -- interrupt a running program                                 
  CTRL-D        -- on a blank line, do a soft reset of the board               
  CTRL-E        -- on a blank line, enter paste mode                           
                                                                                
For further help on a specific object, type help(obj)                          
For a list of available modules, type help('modules')                          
>>> help('modules')                                                            
__main__          gc                ubinascii         upysh                    
_boot             inisetup          ubluetooth        urandom                  
_onewire          machine           ucollections      ure                      
_thread           math              ucryptolib        urequests                
_uasyncio         micropython       uctypes           uselect                  
_webrepl          neopixel          uerrno            usocket                  
apa106            network           uhashlib          ussl                     
btree             ntptime           uheapq            ustruct                  
builtins          onewire           uio               usys                     
cmath             uarray            ujson             utime                    
dht               uasyncio/__init__ umqtt/robust      utimeq                   
ds18x20           uasyncio/core     umqtt/simple      uwebsocket               
esp               uasyncio/event    uos               uzlib                    
esp32             uasyncio/funcs    upip              webrepl                  
flashbdev         uasyncio/lock     upip_utarfile     webrepl_setup            
framebuf          uasyncio/stream   uplatform         websocket_helper         
Plus any modules on the filesystem                                             
>>> 
```

## Blink LED

```python
from machine import Timer

tim0 = Timer(0)
tim0.init(period=5000, mode=Timer.ONE_SHOT, callback=lambda t:print(0))

tim1 = Timer(1)
tim1.init(period=2000, mode=Timer.PERIODIC, callback=lambda t:print(1))
```

## Blink LED

Add a LED on pin 15

```python
import time
from machine import Pin
led=Pin(15,Pin.OUT)
 
while True:
  led.value(1)
  time.sleep(0.5)
  led.value(0)
  time.sleep(0.5)
```

## ADC

```python
from machine import ADC

adc = ADC(pin)        # create an ADC object acting on a pin
val = adc.read_u16()  # read a raw analog value in the range 0-65535
val = adc.read_uv()   # read an analog value in microvolts
```

## Get temperature on DS1820 OneWire sensor

```python
from machine import Pin
import onewire

ow = onewire.OneWire(Pin(12)) # create a OneWire bus on GPIO12
ow.scan()               # return a list of devices on the bus
ow.reset()              # reset the bus

import time, ds18x20

ds = ds18x20.DS18X20(ow)
roms = ds.scan()
ds.convert_temp()
time.sleep_ms(750)
for rom in roms:
    print(ds.read_temp(rom))
```

## GPIO

## GPS

```python
TODO
```

* https://github.com/inmcm/micropyGPS
* https://github.com/boneskull/micropython-nmea/
* https://stm32python.gitlab.io/fr/docs/Micropython/grove/gps

## Scan Wifi networks

```python
import network
station = network.WLAN(network.STA_IF)
station.active(True)
n = station.scan()
print('Wifi networks around:')
for i in n:
  print(i[0], i[2], i[3], 'dBm')
```

## Connect to a Wifi network

## NTP Time and RTC

## HTTP GET

## MQTT subscriber and publisher

## SDCard

```python
import machine, os

# Slot 2 uses pins sck=18, cs=5, miso=19, mosi=23
sd = machine.SDCard(slot=2)
os.mount(sd, "/sd")  # mount

os.listdir('/sd')    # list directory contents

os.umount('/sd')     # eject
```

## LoRa SX1280

## WebREPL (web browser interactive prompt)¶

WebREPL (REPL over WebSockets, accessible via a web browser) is an experimental feature available in ESP32 port. Download web client from https://github.com/micropython/webrepl (hosted version available at http://micropython.org/webrepl), and configure it by executing:

```python
import webrepl_setup
import webrepl
webrepl.start(password='mypass')
```

## Deepsleep

```python
import machine

# configure RTC.ALARM0 to be able to wake the device
rtc = machine.RTC()
rtc.irq(trigger=rtc.ALARM0, wake=machine.DEEPSLEEP)

# set RTC.ALARM0 to fire after 10 seconds (waking the device)
rtc.alarm(rtc.ALARM0, 10000)

# put the device to sleep
machine.deepsleep()
```

Note that when the chip wakes from a deep-sleep it is completely reset, including all of the memory. The boot scripts will run as usual and you can put code in them to check the reset cause to perhaps do something different if the device just woke from a deep-sleep. For example, to print the reset cause you can use:

```python
if machine.reset_cause() == machine.DEEPSLEEP_RESET:
    print('woke from a deep sleep')
else:
    print('power on or hard reset')
```

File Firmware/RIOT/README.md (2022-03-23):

# Firmware based on RIOT

## SX1280 driver
The driver is currently here:

* https://github.com/thingsat/RIOT/tree/pr/sx1280
* https://github.com/thingsat/RIOT/tree/pr/sx1280/tests/driver_sx1280

It has been tested on [STM32 Nucleo boards](https://github.com/thingsat/RIOT/blob/pr/sx1280/tests/driver_sx1280/README.md#tested-boards).

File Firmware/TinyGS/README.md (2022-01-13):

# TinyGS Firmware for LoRa 2.4 GHz

The beta firmware since July support the 2.4Ghz module (sx1280):
https://github.com/G4lile0/tinyGS/tree/beta

Using board templates you can configure it for any pinout:
https://github.com/G4lile0/tinyGS/wiki/Board-Templates

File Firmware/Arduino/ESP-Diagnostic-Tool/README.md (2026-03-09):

# ESP8266/ESP32 Diagnostic Utility

https://github.com/romkey/ESP-Diagnostic-Tool/blob/master/src/main.cpp

https://i2cdevices.org/devices

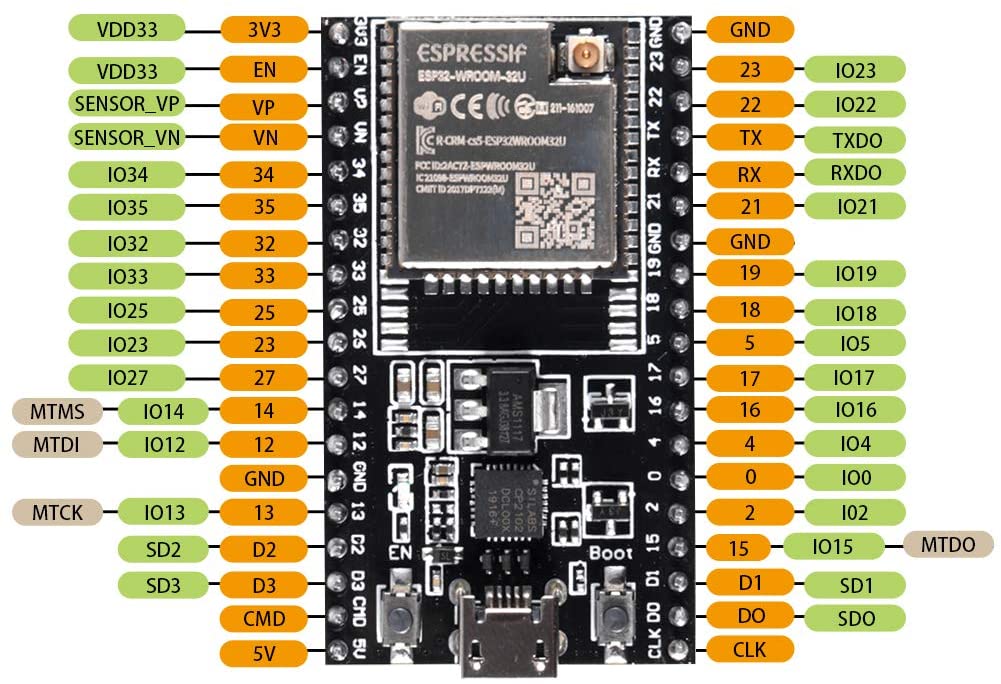
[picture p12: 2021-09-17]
images/ESP32-WROOM-32U-38pins-pinout.jpg

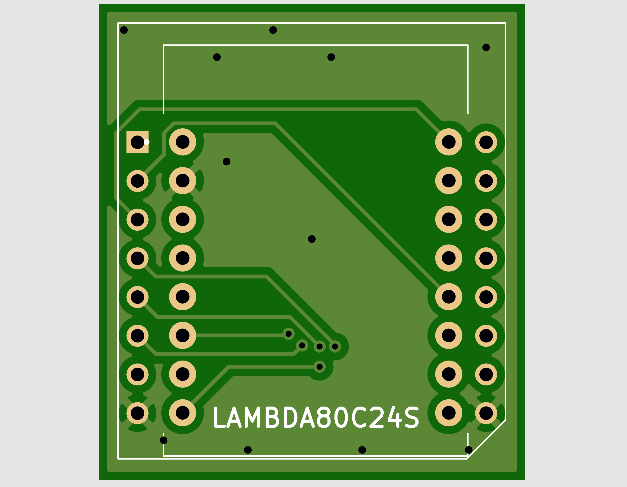
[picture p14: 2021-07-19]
Mikrobus_Board_Lambda80C/Picture/Lambda80_Board_Top.PNG

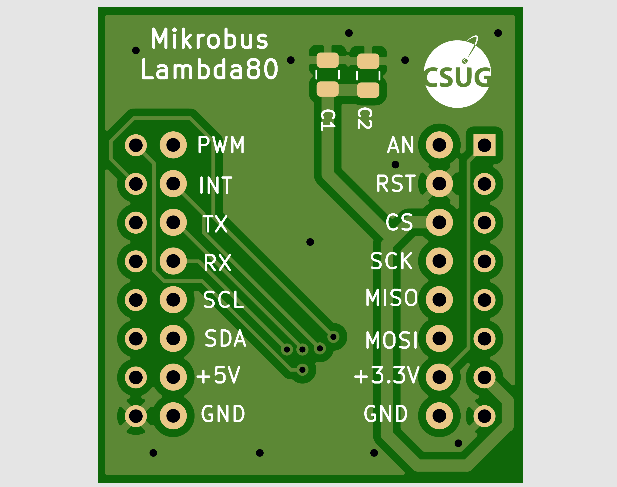
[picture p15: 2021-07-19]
Mikrobus_Board_Lambda80C/Picture/Lambda80_Board_Bottom.PNG

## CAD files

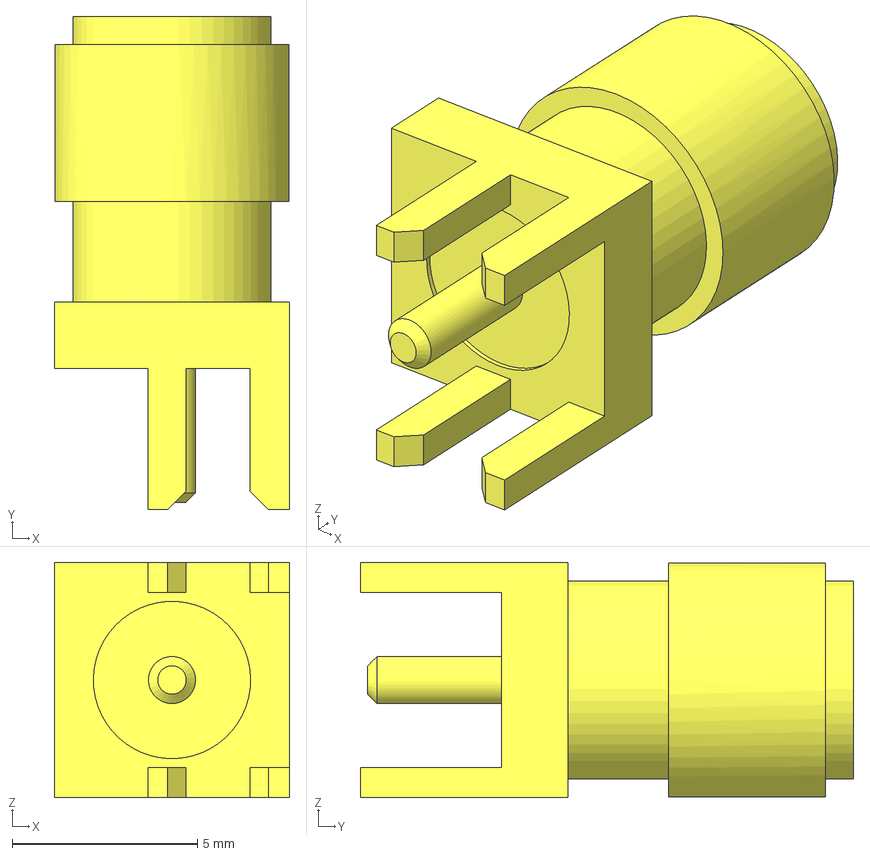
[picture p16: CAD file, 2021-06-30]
Board_Tinysgs_2.4GHz_V1/Lib & Fp/SMA-J-P-H-ST-EM1/SMA-J-P-H-ST-EM1.step
6.35 x 13.3 x 6.35 mm

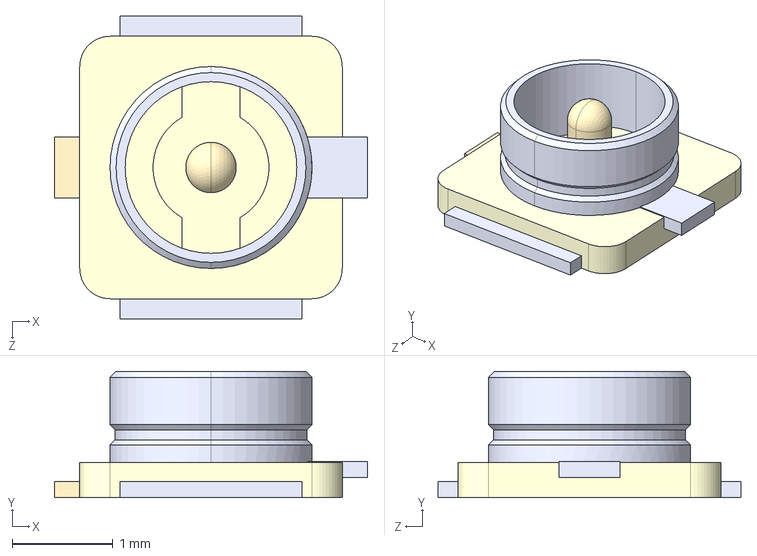
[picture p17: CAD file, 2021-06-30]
Board_Tinysgs_2.4GHz_V1/Lib & Fp/U.FL-R-SMT_01_/U.FL-R-SMT_01_.step
3.10 x 1.25 x 3.00 mm

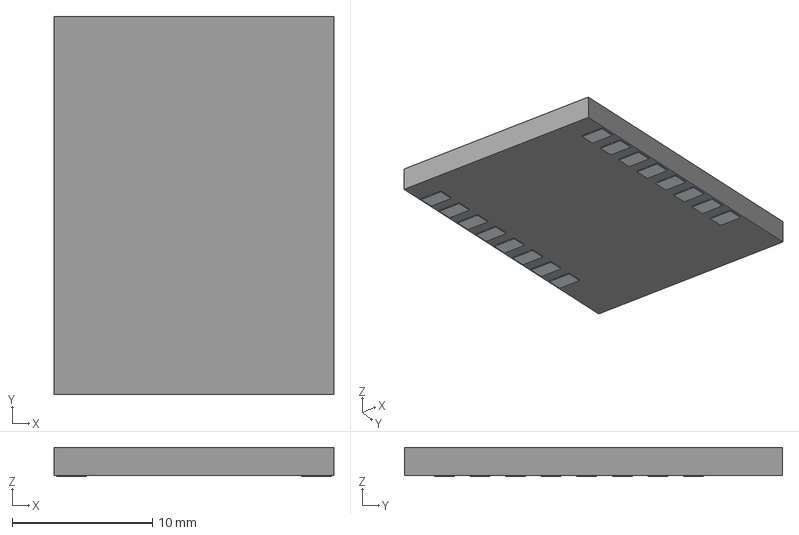
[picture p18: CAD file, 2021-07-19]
Mikrobus_Board_Lambda80C/Lib & Fp/LIB_LAMBDA80C-24S/LAMBDA80C-24S/3D/LAMBDA80C-24S.stp
19.9 x 27.0 x 2.10 mm
Pins

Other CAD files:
Mikrobus_Board_Lambda80C/Lib & Fp/LIB_LAMBDA80C-24S/LAMBDA80C-24S/3D/LAMBDA80C-24S.stl
Mikrobus_Board_Lambda80C/Lib & Fp/LIB_LAMBDA80C-24S/LAMBDA80C-24S/Allegro/lambda80c24s.psm
Mikrobus_Board_Lambda80C/Lib & Fp/LIB_LAMBDA80C-24S/LAMBDA80C-24S/DEHDL/lambda80c_24s/chips/chips.prt
Mikrobus_Board_Lambda80C/Lib & Fp/LIB_MIKROE-924/MIKROE-924/Allegro/mikroe924.psm
Mikrobus_Board_Lambda80C/Lib & Fp/LIB_MIKROE-924/MIKROE-924/DEHDL/mikroe_924/chips/chips.prt

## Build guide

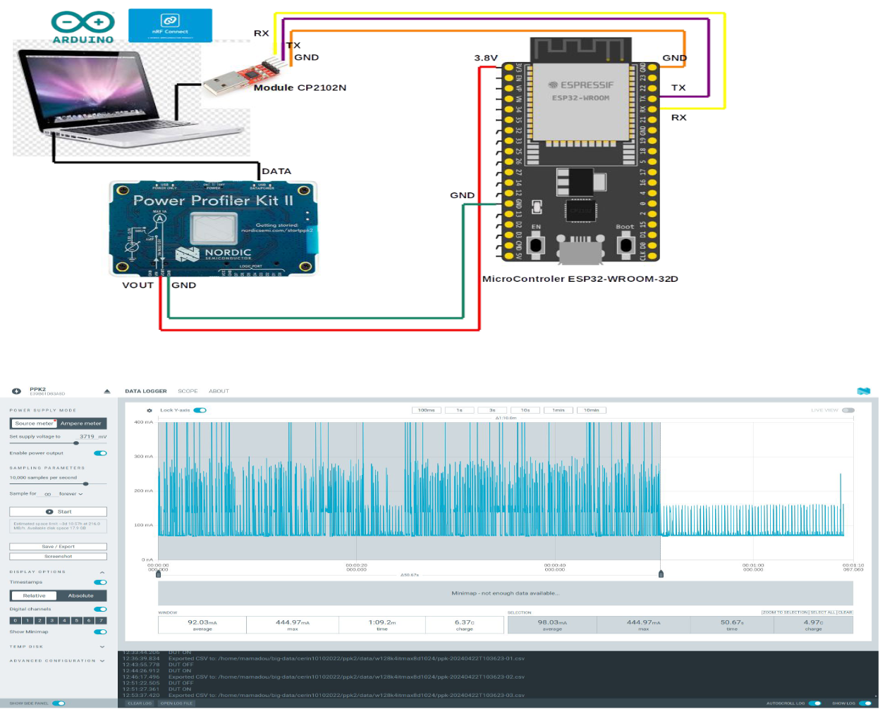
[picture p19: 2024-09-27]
Firmware/Arduino/nrf-ppk2/setup.png

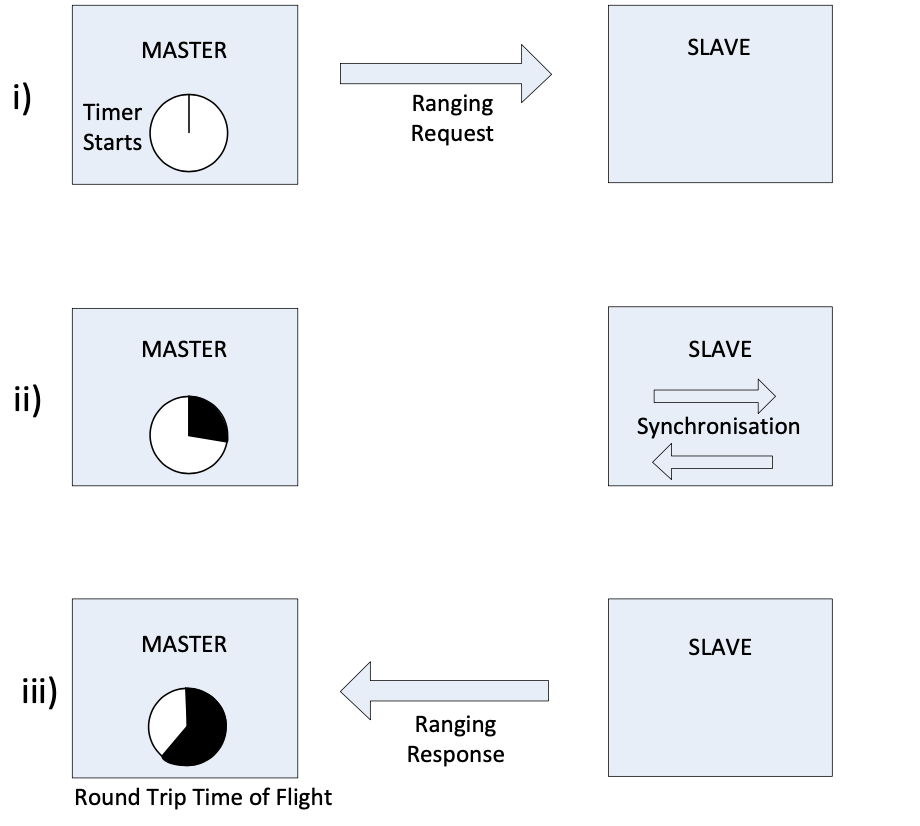
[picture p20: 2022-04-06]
Firmware/Arduino/SX1280_Ranging/SX1280_Ranging_Basic_Operations.png

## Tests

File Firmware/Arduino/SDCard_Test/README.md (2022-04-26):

# TinyGS 2G4 :: SDCard breakout

Read https://randomnerdtutorials.com/esp32-microsd-card-arduino/

Import library https://github.com/espressif/arduino-esp32/tree/master/libraries/SD as a Zip file

Connect the SD card breakout to the following pins of the ESP32 Wroon 32U's double row headers

| SD Card | ESP32 Wroom 32U | Header |
|---|---|---|
| D2 | - | - |
| D3/CS | SS (IO5) | Pin29|
| CMD/MOSI | MOSI (IO23)| Pin21|
| VSS/GND | GND (GND3)| Pin20|
| VDD/3V3 | 3.3V (3V3)| Pin1|
| CLK | SCK (IO12)| Pin13|
| VSS/GND | - | - |
| D0/MISO | MISO (IO19)| Pin27|
| D1 | - | - |

Build and flash the sketch SDCard_Test

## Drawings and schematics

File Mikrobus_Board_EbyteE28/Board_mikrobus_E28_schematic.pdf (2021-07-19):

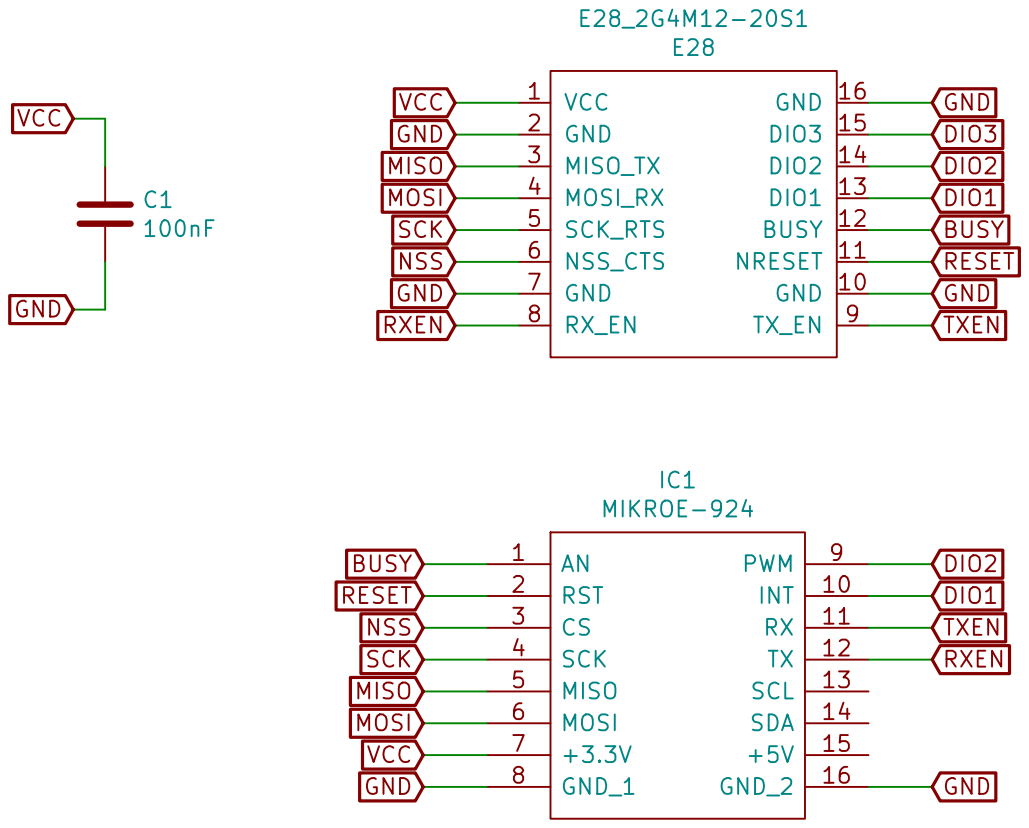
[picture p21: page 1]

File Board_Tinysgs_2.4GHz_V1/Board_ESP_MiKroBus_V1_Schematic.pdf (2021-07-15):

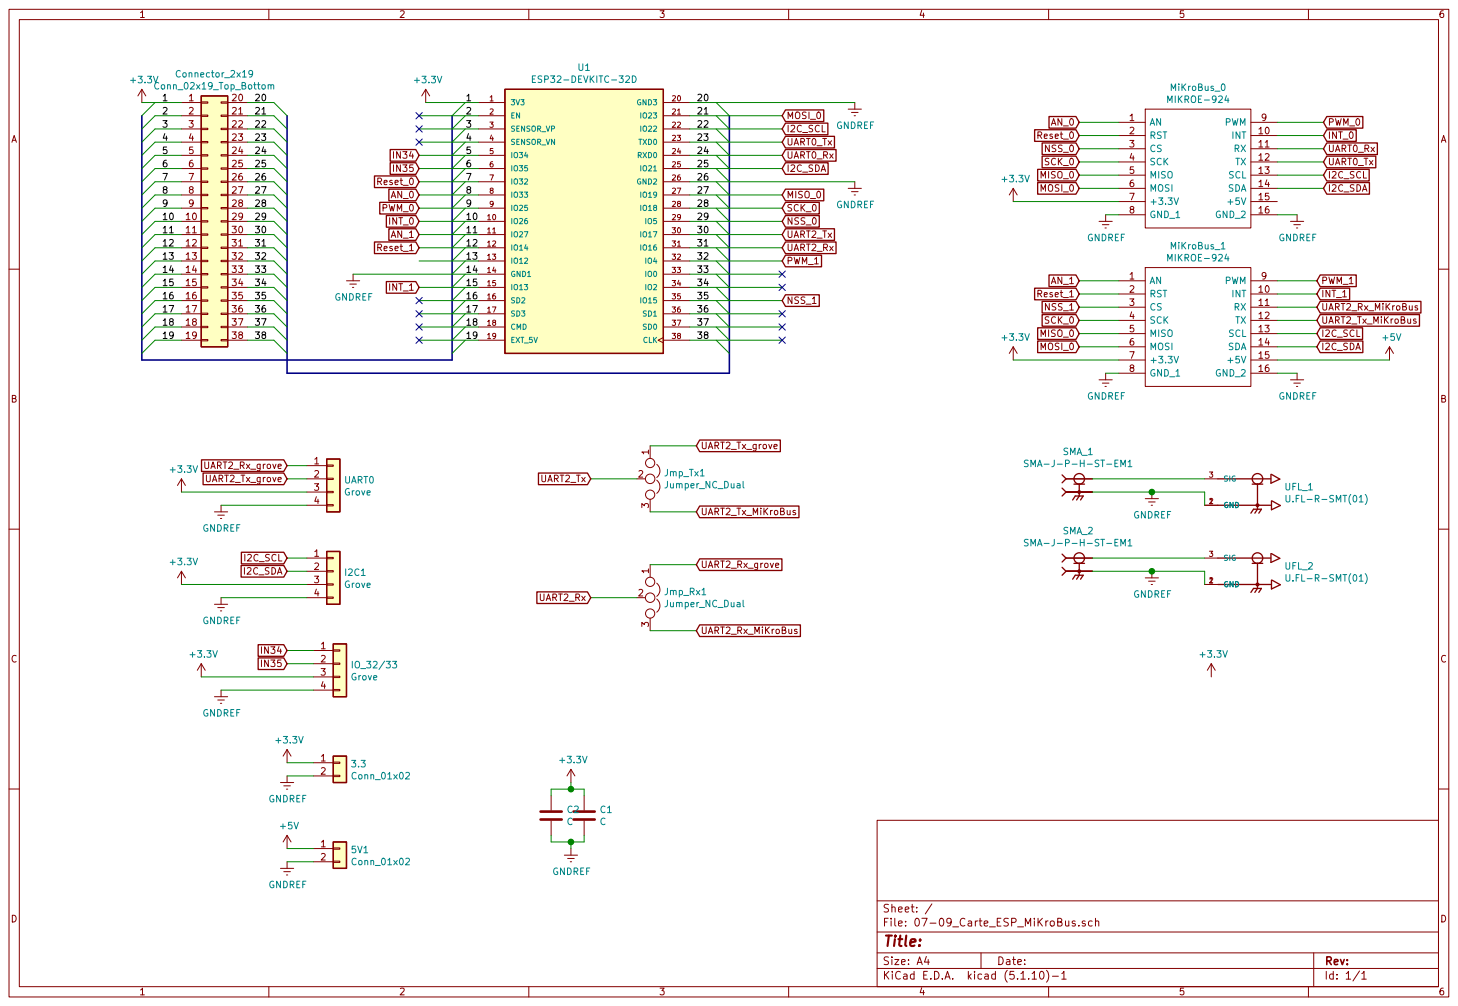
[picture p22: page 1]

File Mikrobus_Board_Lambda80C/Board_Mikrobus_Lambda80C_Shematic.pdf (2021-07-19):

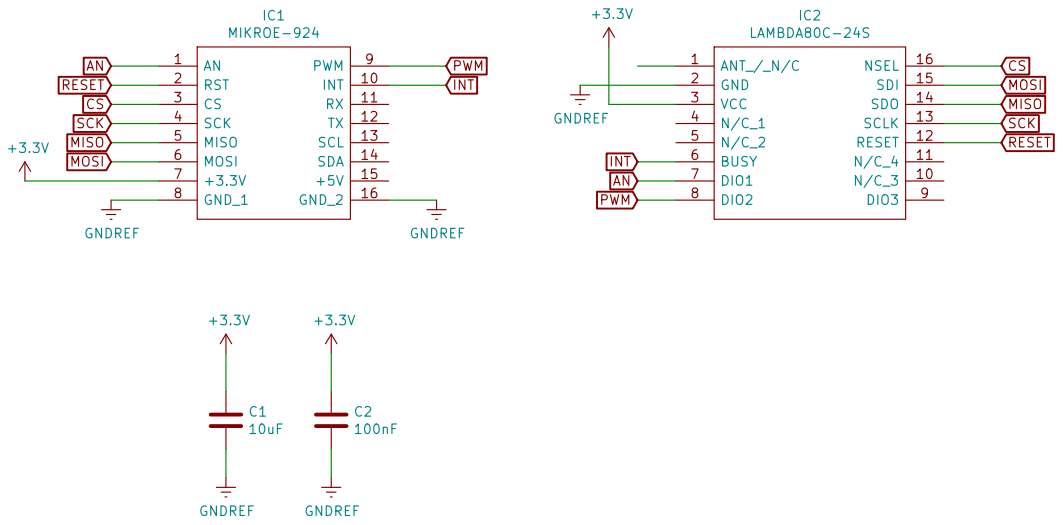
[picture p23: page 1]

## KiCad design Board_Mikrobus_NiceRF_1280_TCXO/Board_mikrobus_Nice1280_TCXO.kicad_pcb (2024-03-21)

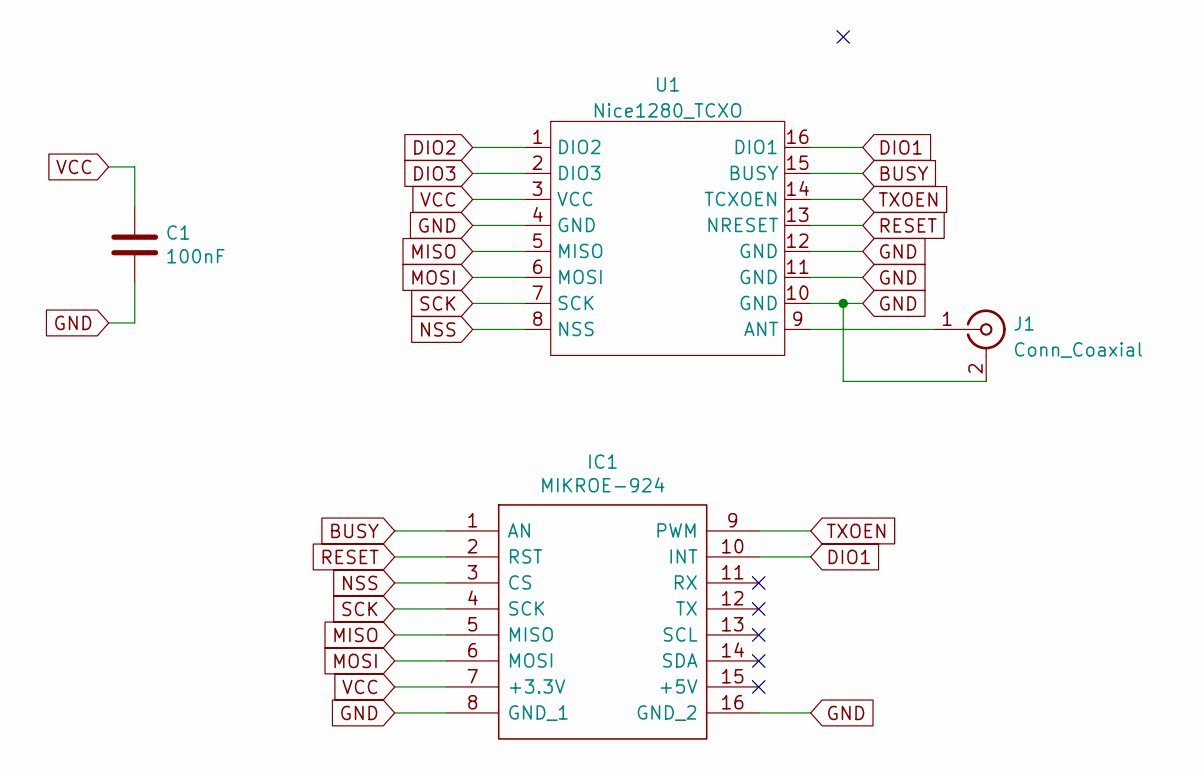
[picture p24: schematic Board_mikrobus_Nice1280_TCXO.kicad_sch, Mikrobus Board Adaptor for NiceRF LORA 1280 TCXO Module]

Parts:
C1: 100nF; C_0805_2012Metric_Pad1.18x1.45mm_HandSolder
IC1: MIKROE-924; MIKROE924; Manufacturer_Part_Number MIKROE-924; Mouser Part Number 932-MIKROE-924
J1: Conn_Coaxial; U.FL_Molex_MCRF_73412-0110_Vertical
U1: Nice1280_TCXO; HOPERF_RFM9XW_SMD

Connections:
BUSY: IC1.1 (AN), U1.15 (BUSY)
DIO1: IC1.10 (INT), U1.16 (DIO1)
DIO2: U1.1 (DIO2)
DIO3: U1.2 (DIO3)
GND: C1.2, IC1.8 (GND_1), IC1.16 (GND_2), J1.2 (Ext), U1.4 (GND), U1.10 (GND), U1.11 (GND), U1.12 (GND)
MISO: IC1.5 (MISO), U1.5 (MISO)
MOSI: IC1.6 (MOSI), U1.6 (MOSI)
NSS: IC1.3 (CS), U1.8 (NSS)
unnamed: J1.1 (In), U1.9 (ANT)
RESET: IC1.2 (RST), U1.13 (NRESET)
SCK: IC1.4 (SCK), U1.7 (SCK)
TXOEN: IC1.9 (PWM), U1.14 (TCXOEN)
VCC: C1.1, IC1.7 (+3.3V), U1.3 (VCC)

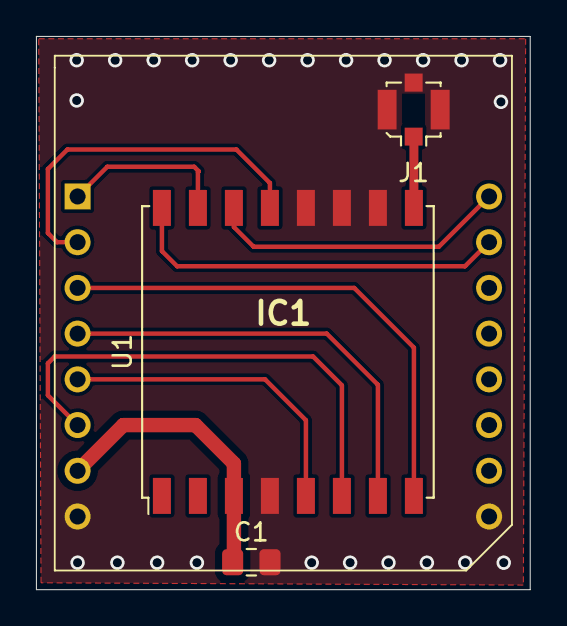
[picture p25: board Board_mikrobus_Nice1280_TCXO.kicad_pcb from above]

Board: 2 copper layers, 27.4 x 30.7 mm, 4 parts (0 on the bottom side), 11 nets.

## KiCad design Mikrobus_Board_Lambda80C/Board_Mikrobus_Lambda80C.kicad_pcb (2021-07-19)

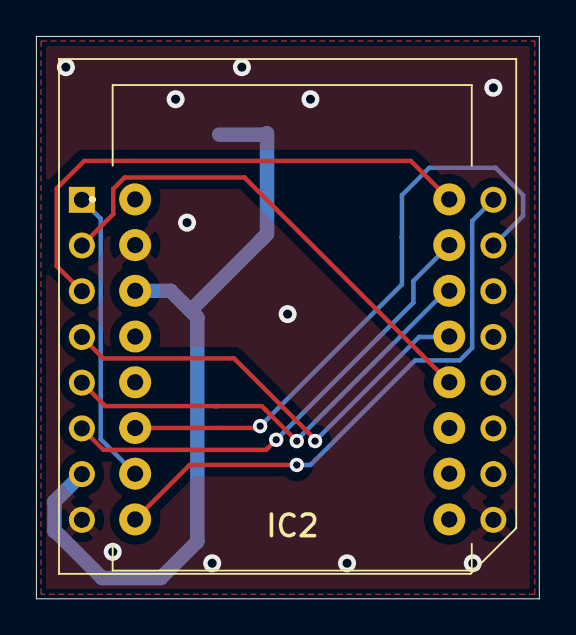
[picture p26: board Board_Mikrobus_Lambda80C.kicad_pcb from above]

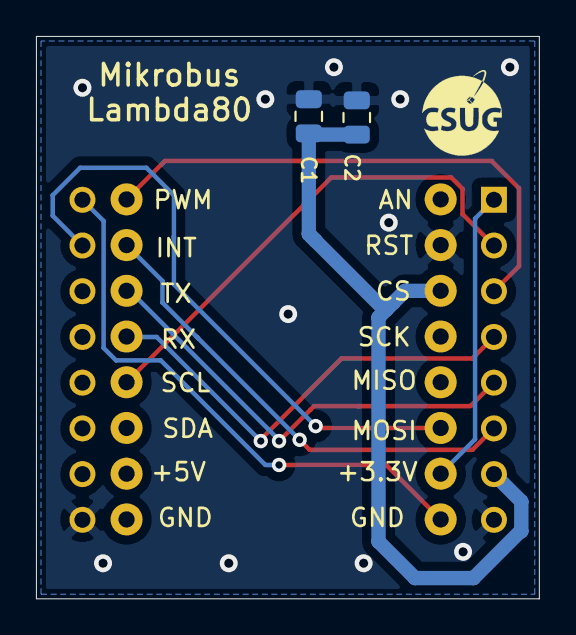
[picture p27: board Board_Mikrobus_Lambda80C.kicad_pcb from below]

Board: 2 copper layers, 27.9 x 31.2 mm, 4 parts (2 on the bottom side), 10 nets.

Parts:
C1: 10uF; C_0805_2012Metric
C2: 100nF; C_0805_2012Metric
IC1: MIKROE-924; MIKROE924
IC2: LAMBDA80C-24S; Lambda80C_24S-traversant

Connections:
+3V3: C1.1, C2.1, IC1.7, IC2.3
AN: IC1.1, IC2.7
CS: IC1.3, IC2.16
GNDREF: C1.2, C2.2, IC1.8, IC1.16, IC2.2
INT: IC1.10, IC2.6
MISO: IC1.5, IC2.14
MOSI: IC1.6, IC2.15
PWM: IC1.9, IC2.8
RESET: IC1.2, IC2.12
SCK: IC1.4, IC2.13

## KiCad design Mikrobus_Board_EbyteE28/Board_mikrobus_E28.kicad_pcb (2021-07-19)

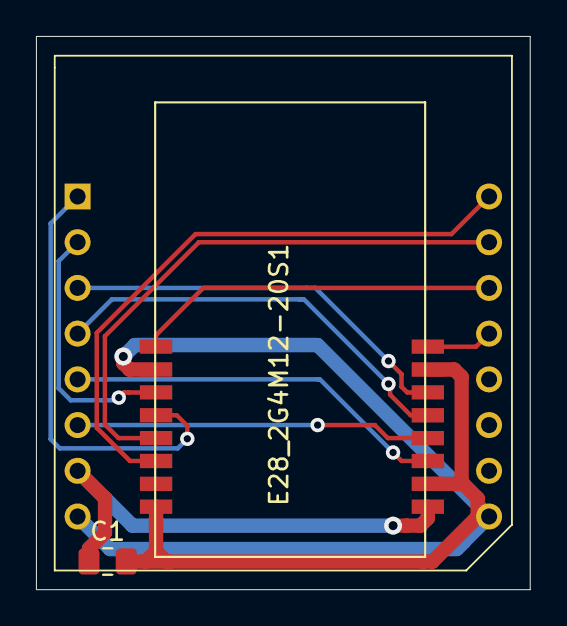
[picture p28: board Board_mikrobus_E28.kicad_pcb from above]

Board: 2 copper layers, 27.4 x 30.7 mm, 3 parts (0 on the bottom side), 12 nets.

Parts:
C1: 100nF; C_0805_2012Metric_Pad1.18x1.45mm_HandSolder
E28_2G4M12-20S1: E28; E28-2G4M12-20S
IC1: MIKROE-924; MIKROE924

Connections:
BUSY: E28_2G4M12-20S1.12, IC1.1
DIO1: E28_2G4M12-20S1.13, IC1.10
DIO2: E28_2G4M12-20S1.14, IC1.9
GND: C1.2, E28_2G4M12-20S1.2, E28_2G4M12-20S1.7, E28_2G4M12-20S1.10, E28_2G4M12-20S1.16, IC1.8, IC1.16
MISO: E28_2G4M12-20S1.3, IC1.5
MOSI: E28_2G4M12-20S1.4, IC1.6
NSS: E28_2G4M12-20S1.6, IC1.3
RESET: E28_2G4M12-20S1.11, IC1.2
RXEN: E28_2G4M12-20S1.8, IC1.12
SCK: E28_2G4M12-20S1.5, IC1.4
TXEN: E28_2G4M12-20S1.9, IC1.11
VCC: C1.1, E28_2G4M12-20S1.1, IC1.7

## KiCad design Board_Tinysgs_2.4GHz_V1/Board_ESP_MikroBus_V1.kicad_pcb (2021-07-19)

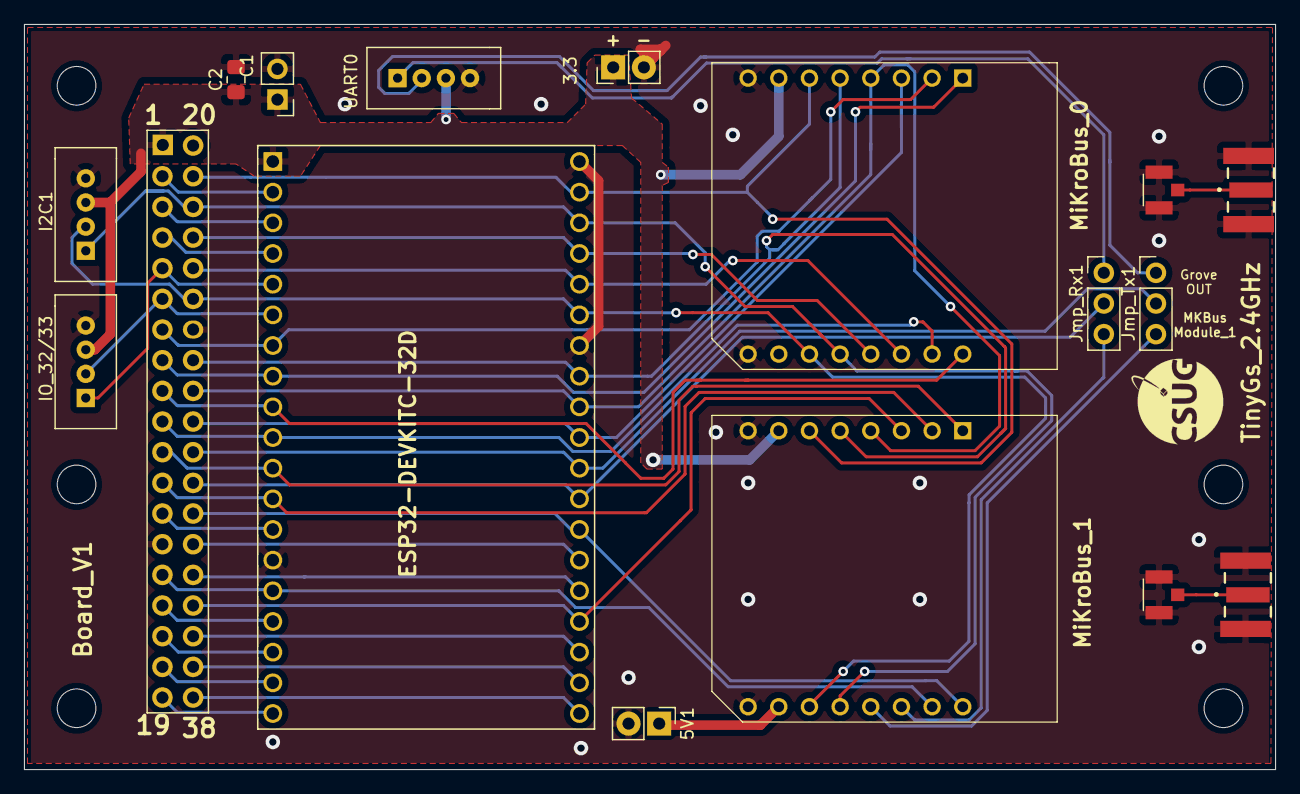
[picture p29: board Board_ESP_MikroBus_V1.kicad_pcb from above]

Board: 2 copper layers, 103.6 x 61.7 mm, 17 parts (0 on the bottom side), 43 nets.

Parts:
3.3, 5V1: Conn_01x02; PinHeader_1x02_P2.54mm_Vertical
C1: C; PinHeader_1x02_P2.54mm_Vertical
C2: C; C_0805_2012Metric_Pad1.18x1.45mm_HandSolder
Connector_2x19: Conn_02x19_Top_Bottom; conn_2x19_2.54mm_top_bot
I2C1: Grove; Grove_4pin-2.00mm
IO_32/33: Grove; Grove_4pin-2.00mm
Jmp_Rx1: Jumper_NC_Dual; PinHeader_1x03_P2.54mm_Vertical
Jmp_Tx1: Jumper_NC_Dual; PinHeader_1x03_P2.54mm_Vertical
MiKroBus_0, MiKroBus_1: MIKROE-924; MIKROE924
SMA_1, SMA_2: SMA-J-P-H-ST-EM1; SAMTEC_SMA-J-P-H-ST-EM1
U1: ESP32-DEVKITC-32D; MODULE_ESP32-DEVKITC-V4-32D
UART0: Grove; Grove_4pin-2.00mm
UFL_1, UFL_2: U.FL-R-SMT(01); HRS_U.FL-R-SMT(01)

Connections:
+3V3: 3.3.1, C1.1, C2.1, Connector_2x19.1, I2C1.3, IO_32/33.3, MiKroBus_0.7, MiKroBus_1.7, U1.1, UART0.3
+5V: 5V1.1, MiKroBus_1.15
/2: Connector_2x19.2, U1.2
/3: Connector_2x19.3, U1.3
/4: Connector_2x19.4, U1.4
/13: Connector_2x19.13, U1.13
/16: Connector_2x19.16, U1.16
/17: Connector_2x19.17, U1.17
/18: Connector_2x19.18, U1.18
/19: Connector_2x19.19, U1.19
/33: Connector_2x19.33, U1.33
/34: Connector_2x19.34, U1.34
/36: Connector_2x19.36, U1.36
/37: Connector_2x19.37, U1.37
/38: Connector_2x19.38, U1.38
AN_0: Connector_2x19.8, MiKroBus_0.1, U1.8
AN_1: Connector_2x19.11, MiKroBus_1.1, U1.11
GNDREF: 3.3.2, 5V1.2, C1.2, C2.2, Connector_2x19.14, Connector_2x19.20, Connector_2x19.26, I2C1.4, IO_32/33.4, MiKroBus_0.8, MiKroBus_0.16, MiKroBus_1.8, MiKroBus_1.16, SMA_1.2_1, SMA_1.2_2, SMA_1.3_1, SMA_1.3_2, SMA_2.2_1, SMA_2.2_2, SMA_2.3_1, SMA_2.3_2, U1.14, U1.20, U1.26, UART0.4, UFL_1.1, UFL_1.2, UFL_2.1, UFL_2.2
I2C_SCL: Connector_2x19.22, I2C1.1, MiKroBus_0.13, MiKroBus_1.13, U1.22
I2C_SDA: Connector_2x19.25, I2C1.2, MiKroBus_0.14, MiKroBus_1.14, U1.25
IN34: Connector_2x19.5, IO_32/33.1, U1.5
IN35: Connector_2x19.6, IO_32/33.2, U1.6
INT_0: Connector_2x19.10, MiKroBus_0.10, U1.10
INT_1: Connector_2x19.15, MiKroBus_1.10, U1.15
MISO_0: Connector_2x19.27, MiKroBus_0.5, MiKroBus_1.5, U1.27
MOSI_0: Connector_2x19.21, MiKroBus_0.6, MiKroBus_1.6, U1.21
NSS_0: Connector_2x19.29, MiKroBus_0.3, U1.29
NSS_1: Connector_2x19.35, MiKroBus_1.3, U1.35
unnamed: SMA_1.1, UFL_1.3
unnamed: SMA_2.1, UFL_2.3
PWM_0: Connector_2x19.9, MiKroBus_0.9, U1.9
PWM_1: Connector_2x19.32, MiKroBus_1.9, U1.32
Reset_0: Connector_2x19.7, MiKroBus_0.2, U1.7
Reset_1: Connector_2x19.12, MiKroBus_1.2, U1.12
SCK_0: Connector_2x19.28, MiKroBus_0.4, MiKroBus_1.4, U1.28
UART0_Rx: Connector_2x19.24, MiKroBus_0.11, U1.24
UART0_Tx: Connector_2x19.23, MiKroBus_0.12, U1.23
UART2_Rx: Connector_2x19.31, Jmp_Rx1.2, U1.31
UART2_Rx_MiKroBus: Jmp_Rx1.3, MiKroBus_1.11
UART2_Rx_grove: Jmp_Rx1.1, UART0.1
UART2_Tx: Connector_2x19.30, Jmp_Tx1.2, U1.30
UART2_Tx_MiKroBus: Jmp_Tx1.3, MiKroBus_1.12
UART2_Tx_grove: Jmp_Tx1.1, UART0.2

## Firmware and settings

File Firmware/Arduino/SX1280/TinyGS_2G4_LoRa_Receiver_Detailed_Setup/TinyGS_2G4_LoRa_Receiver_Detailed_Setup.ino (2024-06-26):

/*******************************************************************************************************
  Programs for Arduino - Copyright of the author Stuart Robinson - 19/03/20

  This program is supplied as is, it is up to the user of the program to decide if the program is
  suitable for the intended purpose and free from errors. 
*******************************************************************************************************/

/*******************************************************************************************************
  Program Operation - This is a program that demonstrates the detailed setup of a LoRa test receiver.
  The program listens for incoming packets using the lora settings in the 'Settings.h' file. The pins 
  to access the lora device need to be defined in the 'Settings.h' file also.

  There is a printout on the Arduino IDE Serial Monitor of the valid packets received, the packet is 
  assumed to be in ASCII printable text, if it's not ASCII text characters from 0x20 to 0x7F, expect 
  weird things to happen on the Serial Monitor. The LED will flash for each packet received and the 
  buzzer will sound, if fitted.

  Sample serial monitor output;

  7s  Hello World 1234567890*,CRC,DAAB,RSSI,-52dBm,SNR,9dB,Length,23,Packets,5,Errors,0,IRQreg,50

  If there is a packet error it might look like this, which is showing a CRC error,

  968s PacketError,RSSI,-87dBm,SNR,-11dB,Length,23,Packets,613,Errors,2,IRQreg,70,IRQ_HEADER_VALID,IRQ_CRC_ERROR,IRQ_RX_DONE
  
  Serial monitor baud rate is set at 9600.
*******************************************************************************************************/

#define Program_Version "V1.0"

#include <SPI.h>                                 //the lora device is SPI based so load the SPI library
#include "SX128XLT_SW.h"                            //include the appropriate library   


#ifndef BALLOON
#define BALLOON               1
// #define MULTITECH_ISM2400     1
#endif

// Define here the S1280 Mikrobus you have plugged on the TinyGS 2G4 station
#define MIKROBUS0_LAMBDA80
//#define MIKROBUS1_LAMBDA80
//#define MIKROBUS0_E28
//#define MIKROBUS1_E28
//#define MIKROBUS0_NICERF
//#define MIKROBUS1_NICERF

#include "Settings.h"                            //include the setiings file, frequencies, LoRa settings etc   

SX128XLT_SW LT;                                     //create a library class instance called LT

uint32_t RXpacketCount;
uint32_t errors;

uint8_t RXBUFFER[RXBUFFER_SIZE];                 //create the buffer that received packets are copied into

uint8_t RXPacketL;                               //stores length of packet received
int8_t  PacketRSSI;                              //stores RSSI of received packet
int8_t  PacketSNR;                               //stores signal to noise ratio (SNR) of received packet

uint64_t devEUI;

void loop()
{
  RXPacketL = LT.receive(RXBUFFER, RXBUFFER_SIZE, 60000, WAIT_RX); //wait for a packet to arrive with 60seconds (60000mS) timeout

  digitalWrite(LED1, HIGH);                      //something has happened

  if (BUZZER > 0)                                //turn buzzer on
  {
    digitalWrite(BUZZER, HIGH);
  }

  PacketRSSI = LT.readPacketRSSI();              //read the recived RSSI value
  PacketSNR = LT.readPacketSNR();                //read the received SNR value

  if (RXPacketL == 0)                            //if the LT.receive() function detects an error, RXpacketL is 0
  {
    packet_is_Error();
  }
  else
  {
    packet_is_OK();
  }

  if (BUZZER > 0)
  {
    digitalWrite(BUZZER, LOW);                   //buzzer off
  }

  digitalWrite(LED1, LOW);                       //LED off

  Serial.println();
}

static void printf_ba(const uint8_t *ba, size_t len, size_t line_size, const char *line_sep) {
	for (unsigned int i = 0; i < len; i++) {
		if (i != 0 && i % line_size == 0) {
			printf("%s", line_sep);
		}
		printf("%02x ", ba[i]);
	}
	printf("%s", line_sep);
}

//static const boolean isASCII = false;

void packet_is_OK()
{
  uint16_t IRQStatus, localCRC;

  IRQStatus = LT.readIrqStatus();                 //read the LoRa device IRQ status register

  RXpacketCount++;

  printElapsedTime();                             //print elapsed time to Serial Monitor
  Serial.print(F("  "));

  localCRC = LT.CRCCCITT(RXBUFFER, RXPacketL, 0xFFFF);  //calculate the CRC, this is the external CRC calculation of the RXBUFFER
  Serial.print(F("CRC="));                       //contents, not the LoRa device internal CRC
  Serial.print(localCRC, HEX);
  Serial.print(F(",RSSI="));
  Serial.print(PacketRSSI);
  Serial.print(F("dBm,SNR="));
  Serial.print(PacketSNR);
  Serial.print(F("dB,Length="));
  Serial.print(RXPacketL);
  Serial.print(F(",Packets="));
  Serial.print(RXpacketCount);
  Serial.print(F(",Errors="));
  Serial.print(errors);
  Serial.print(F(",IRQreg="));
  Serial.print(IRQStatus, HEX);
  Serial.println();
  LT.printASCIIPacket(RXBUFFER, RXPacketL);       //print the packet as ASCII characters
  Serial.println();
  printf_ba(RXBUFFER, RXPacketL, 16, "\n");
}


void packet_is_Error()
{
  uint16_t IRQStatus;
  IRQStatus = LT.readIrqStatus();                   //read the LoRa device IRQ status register

  printElapsedTime();                               //print elapsed time to Serial Monitor

  if (IRQStatus & IRQ_RX_TIMEOUT)                   //check for an RX timeout
  {
    Serial.print(F(" RXTimeout"));
  }
  else
  {
    errors++;
    Serial.print(F(" PacketError"));
    Serial.print(F(",RSSI,"));
    Serial.print(PacketRSSI);
    Serial.print(F("dBm,SNR,"));
    Serial.print(PacketSNR);
    Serial.print(F("dB,Length,"));
    Serial.print(LT.readRXPacketL());               //get the device packet length
    Serial.print(F(",Packets,"));
    Serial.print(RXpacketCount);
    Serial.print(F(",Errors,"));
    Serial.print(errors);
    Serial.print(F(",IRQreg,"));
    Serial.print(IRQStatus, HEX);
    LT.printIrqStatus();                            //print the names of the IRQ registers set
  }

  delay(250);                                       //gives a longer buzzer and LED flash for error 
  
}


void printElapsedTime()
{
  float seconds;
  seconds = millis() / 1000;
  Serial.print(seconds, 0);
  Serial.print(F("s"));
}


void led_Flash(uint16_t flashes, uint16_t delaymS)
{
  uint16_t index;

  for (index = 1; index <= flashes; index++)
  {
    digitalWrite(LED1, HIGH);
    delay(delaymS);
    digitalWrite(LED1, LOW);
    delay(delaymS);
  }
}


void setup()
{
#ifdef ARDUINO_ARCH_ESP32  
  devEUI = ESP.getEfuseMac();
  printf("DevEUI: %llX\n", devEUI);
#else
  devEUI = 0x0102030405060708;
#endif

  pinMode(LED1, OUTPUT);                        //setup pin as output for indicator LED
  led_Flash(2, 125);                            //two quick LED flashes to indicate program start

  Serial.begin(115200);
  Serial.println();
  Serial.print(F(__TIME__));
  Serial.print(F(" "));
  Serial.println(F(__DATE__));
  Serial.println(F(Program_Version));
  Serial.println();
  Serial.println(F("TinyGS 2G4 :: LoRa_Receiver_Detailed_Setup Starting"));
  Serial.println();

  if (BUZZER > 0)
  {
    pinMode(BUZZER, OUTPUT);
    digitalWrite(BUZZER, HIGH);
    delay(50);
    digitalWrite(BUZZER, LOW);
  }

  SPI.begin();

  //SPI beginTranscation is normally part of library routines, but if it is disabled in the library
  //a single instance is needed here, so uncomment the program line below
  //SPI.beginTransaction(SPISettings(8000000, MSBFIRST, SPI_MODE0));

  //setup hardware pins used by device, then check if device is found
  if (LT.begin(NSS, NRESET, RFBUSY, DIO1, DIO2, DIO3, RX_EN, TX_EN, LORA_DEVICE))
  {
    Serial.println(F("LoRa Device found"));
    led_Flash(2, 125);
    delay(1000);
  }
  else
  {
    Serial.println(F("No device responding"));
    while (1)
    {
      led_Flash(50, 50);                                       //long fast speed LED flash indicates device error
    }
  }

  //The function call list below shows the complete setup for the LoRa device using the information defined in the
  //Settings.h file.
  //The 'Setup LoRa device' list below can be replaced with a single function call;
  //LT.setupLoRa(Frequency, Offset, SpreadingFactor, Bandwidth, CodeRate);

  //***************************************************************************************************
  //Setup LoRa device
  //***************************************************************************************************
  LT.setMode(MODE_STDBY_RC);
  LT.setRegulatorMode(USE_LDO);
  LT.setPacketType(PACKET_TYPE_LORA);
  LT.setSyncWord(LORA_MAC_PUBLIC_SYNCWORD);
  LT.setRfFrequency(Frequency, Offset);
  LT.setBufferBaseAddress(0, 0);
  LT.setModulationParams(SpreadingFactor, Bandwidth, CodeRate);
  LT.setPacketParams(LenInSymb, LORA_PACKET_VARIABLE_LENGTH, 255, LORA_CRC_ON, LORA_IQ_UPLINK, 0, 0);
  LT.setDioIrqParams(IRQ_RADIO_ALL, (IRQ_TX_DONE + IRQ_RX_TX_TIMEOUT), 0, 0);
  //***************************************************************************************************


  Serial.println();
  LT.printModemSettingsSW();                                     //reads and prints the configured LoRa settings, useful check
  Serial.println();
  LT.printOperatingSettings();                                 //reads and prints the configured operting settings, useful check
  Serial.println();
  Serial.println();
  LT.printRegisters(0x900, 0x9FF);                             //print contents of device registers, normally 0x900 to 0x9FF
  Serial.println();
  Serial.println();

  Serial.print(F("Receiver ready - RXBUFFER_SIZE "));
  Serial.println(RXBUFFER_SIZE);
  Serial.println();
}

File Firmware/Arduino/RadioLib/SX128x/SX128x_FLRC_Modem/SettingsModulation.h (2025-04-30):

/*******************************************************************************************************
  Programs for Arduino - Copyright of the author Stuart Robinson - 02/03/20

  This program is supplied as is, it is up to the user of the program to decide if the program is
  suitable for the intended purpose and free from errors.
*******************************************************************************************************/

//*******  Setup LoRa Parameters Here ! ***************

// https://github.com/chirpstack/chirpstack/blob/master/chirpstack/configuration/region_ism2400.toml
#define CHIRPSTACK_ISM2400_CHANNEL_1       2403.000000
#define CHIRPSTACK_ISM2400_CHANNEL_2       2479.000000
#define CHIRPSTACK_ISM2400_CHANNEL_3       2425.000000
#define CHIRPSTACK_ISM2400_CHANNEL_RX2     2423.000000
#define CHIRPSTACK_ISM2400_BANDWITH        812.50
#define CHIRPSTACK_ISM2400_SF              12


#define MULTITECH_ISM2400_CHANNEL_1       2422.000000
#define MULTITECH_ISM2400_CHANNEL_2       2425.000000
#define MULTITECH_ISM2400_CHANNEL_3       2479.000000
#define MULTITECH_ISM2400_BANDWITH        812.50
#define MULTITECH_ISM2400_SF              12
#define MULTITECH_ISM2400_CR              0x08 //LORA_CR_LI_4_8
#define MULTITECH_ISM2400_SYNCWORD_PUBLIC (0x12)
#define MULTITECH_ISM2400_LEN_IN_SYMB     (8)


#define LORA_IQ_UPLINK              LORA_IQ_NORMAL
#define LORA_IQ_DOWNLINK            LORA_IQ_NORMAL


#if BALLOON == 1

//LoRa Modem Parameters
#define Frequency 2483.500000                    //frequency of transmissions
#define Offset    0                             //offset frequency for calibration purposes  
#define Bandwidth 812.50                  //LoRa bandwidth
#define SpreadingFactor 12               //LoRa spreading factor
#define CodeRate 5                 //LoRa coding rate
#define PreambleLenInSymb             (8)                           //Preamble length
/*
Sync_word = 0x21,
*/
#define TxPower               10                                        // dBm
#define SyncWord              0x21

#elif MULTITECH_ISM2400 == 1

//LoRa Modem Parameters
#define Frequency                 MULTITECH_ISM2400_CHANNEL_1   //frequency of transmissions
#define Offset 0                                                //offset frequency for calibration purposes  
#define Bandwidth                 MULTITECH_ISM2400_BANDWITH    //LoRa bandwidth
#define SpreadingFactor           MULTITECH_ISM2400_SF          //LoRa spreading factor
#define CodeRate                  MULTITECH_ISM2400_CR          //LoRa coding rate
#define PreambleLenInSymb         MULTITECH_ISM2400_LEN_IN_SYMB //Preamble length

#define TxPower                   10                                        // dBm
#define SyncWord                  RADIOLIB_SX128X_SYNC_WORD_PRIVATE


#else

// defines in     RadioLib/src/modules/SX128x/SX128x.h

#define Frequency             CHIRPSTACK_ISM2400_CHANNEL_1                //frequency of transmissions
#define Offset                0                                           //offset frequency for calibration purposes  
#define Bandwidth             CHIRPSTACK_ISM2400_BANDWITH                 //LoRa bandwidth
#define SpreadingFactor       CHIRPSTACK_ISM2400_SF                       //LoRa spreading factor
#define CodeRate              7             //LoRa coding rate
#define PreambleLenInSymb     (12)                                     //Preamble length
#define TxPower               10                                        // dBm
#define SyncWord              0x34

#endif

#ifndef PACKET_DELAY
#define PACKET_DELAY 1000                  // msec.
#endif

// TODO change in #define
const uint16_t packet_delay = PACKET_DELAY;           // mS delay between packets

#ifndef TXBUFFER_SIZE
#define TXBUFFER_SIZE 255                        // TX buffer size (LoRa frame maximum size is 255)
#endif

#ifndef RXBUFFER_SIZE
#define RXBUFFER_SIZE 255                        // RX buffer size (LoRa frame maximum size is 255)
#endif

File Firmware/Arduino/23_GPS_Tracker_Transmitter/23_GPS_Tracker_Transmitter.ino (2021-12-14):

/*******************************************************************************************************
  Programs for Arduino - Copyright of the author Stuart Robinson - 21/03/20

  This program is supplied as is, it is up to the user of the program to decide if the program is
  suitable for the intended purpose and free from errors.
*******************************************************************************************************/

/*******************************************************************************************************
  Program Operation -  This program is an example of a basic GPS tracker. The program reads the GPS,
  waits for an updated fix and transmits location and altitude, number of satellites in view, the HDOP
  value, the fix time of the GPS and the battery voltage. This transmitter can be also be used to
  investigate GPS performance. At startup there should be a couple of seconds of recognisable text from
  the GPS printed to the serial monitor. If you see garbage or funny characters its likley the GPS baud
  rate is wrong. If the transmitter is turned on from cold, the receiver will pick up the cold fix time,
  which is an indication of GPS performance. The GPS will be powered on for around 4 seconds before the
  timing of the fix starts. Outside with a good view of the sky most GPSs should produce a fix in around
  45 seconds. The number of satellites and HDOP are good indications to how well a GPS is working.

  The program writes direct to the LoRa devices internal buffer, no memory buffer is used.

  The LoRa settings are configured in the Settings.h file.

  The program has the option of using a pin to control the power to the GPS (GPSPOWER), if the GPS module
  or board being used has this feature. To not use this feature set the define for GPSPOWER in the
  Settings.h file to '#define GPSPOWER -1'. Also set the GPSONSTATE and GPSOFFSTATE to the appropriate logic
  levels.

  There is also an option of using a logic pin to turn the resistor divider used to read battery voltage on
  and off. This reduces current used in sleep mode. To use the feature set the define for pin BATVREADON
  in 'Settings.h' to the pin used. If not using the feature set the pin number to -1.

  Serial monitor baud rate is set at 9600.
*******************************************************************************************************/

#define Program_Version "V1.1"
#define authorname "Stuart Robinson"

#include <SPI.h>
#include <SX128XLT.h>

#include "Settings.h"
#include <ProgramLT_Definitions.h>

SX128XLT LT;

#include <TinyGPS++.h>                             //get library here > http://arduiniana.org/libraries/tinygpsplus/
TinyGPSPlus gps;                                   //create the TinyGPS++ object


#ifdef USE_SOFTSERIAL_GPS
#include <SoftwareSerial.h>
SoftwareSerial GPSserial(RXpin, TXpin);
#else
#define GPSserial HardwareSerialPort               //hardware serial port (eg Serial1) is configured in the Settings.h file
#endif


uint8_t TXStatus = 0;                              //used to store current status flag bits of Tracker transmitter (TX)
uint8_t TXPacketL;                                 //length of LoRa packet (TX)
float TXLat;                                       //Latitude from GPS on Tracker transmitter (TX)
float TXLon;                                       //Longitude from GPS on Tracker transmitter (TX)
float TXAlt;                                       //Altitude from GPS on Tracker transmitter (TX)
uint8_t TXSats;                                    //number of GPS satellites seen (TX)
uint32_t TXHdop;                                   //HDOP from GPS on Tracker transmitter (TX)
uint16_t TXVolts;                                  //Volts (battery) level on Tracker transmitter (TX)
uint32_t TXGPSFixTime;                             //GPS fix time in hot fix mode of GPS on Tracker transmitter (TX)
uint32_t TXPacketCount, TXErrorsCount;             //keep count of OK packets and send errors


void loop()
{

  if (gpsWaitFix(WaitGPSFixSeconds))
  {
    sendLocation(TXLat, TXLon, TXAlt, TXHdop, TXGPSFixTime);
    Serial.println();
    Serial.print(F("Waiting "));
    Serial.print(Sleepsecs);
    Serial.println(F("s"));
    delay(Sleepsecs * 1000);                        //this sleep is used to set overall transmission cycle time
  }
  else
  {
    send_Command(NoFix);                            //send notification of no GPS fix.
  }
}


bool gpsWaitFix(uint32_t waitSecs)
{
  //waits a specified number of seconds for a fix, returns true for good fix
  uint32_t endwaitmS, GPSonTime;
  bool GPSfix = false;
  float tempfloat;
  uint8_t GPSchar;

  GPSonTime = millis();
  GPSserial.begin(9600);                         //start GPSserial

  Serial.print(F("Wait GPS Fix "));
  Serial.print(waitSecs);
  Serial.println(F("s"));

  endwaitmS = millis() + (waitSecs * 1000);

  while (millis() < endwaitmS)
  {
    if (GPSserial.available() > 0)
    {
      GPSchar = GPSserial.read();
      gps.encode(GPSchar);
    }

    if (gps.location.isUpdated() && gps.altitude.isUpdated())
    {
      GPSfix = true;
      Serial.print(F("Have GPS Fix "));
      TXGPSFixTime = millis() - GPSonTime;
      Serial.print(TXGPSFixTime);
      Serial.println(F("mS"));

      TXLat = gps.location.lat();
      TXLon = gps.location.lng();
      TXAlt = gps.altitude.meters();
      TXSats = gps.satellites.value();
      TXHdop = gps.hdop.value();
      tempfloat = ( (float) TXHdop / 100);

      Serial.print(TXLat, 5);
      Serial.print(F(","));
      Serial.print(TXLon, 5);
      Serial.print(F(","));
      Serial.print(TXAlt, 1);
      Serial.print(F(","));
      Serial.print(TXSats);
      Serial.print(F(","));
      Serial.print(tempfloat, 2);
      Serial.println();

      break;                                  //exit while loop reading GPS
    }
  }

  //if here then there has either been a fix or no fix and a timeout

  if (GPSfix)
  {
    setStatusByte(GPSFix, 1);                 //set status bit to flag a GPS fix
  }
  else
  {
    setStatusByte(GPSFix, 0);                 //set status bit to flag no fix
    Serial.println();
    Serial.println(F("Timeout - No GPSFix"));
    Serial.println();
    GPSfix = false;
  }

  GPSserial.end();                            //serial RX interrupts interfere with SPI, so stop GPSserial
  return GPSfix;
}
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

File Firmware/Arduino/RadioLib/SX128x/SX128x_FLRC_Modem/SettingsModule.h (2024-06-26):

//*******  Setup hardware pin definitions here ! ***************

//These are the pin definitions for TinyGS 2G4 mikrobus modules
// https://github.com/thingsat/tinygs_2g4station/tree/main/Board_Tinysgs_2.4GHz_V1


#define SCK       18                                  //SCK on SPI3
#define MISO      19                                  //MISO on SPI3 
#define MOSI      23                                  //MOSI on SPI3 

#define NSS_0     5                                   //select pin on LoRa device
#define NSS_1     15                                   //select pin on LoRa device

#define AN_0      33
#define RESET_0   32
#define PWM_0     25
#define INT_0     26

#define AN_1      27
#define RESET_1   14
#define PWM_1     04
#define INT_1     13



#if defined(MIKROBUS0_E28) || defined(MIKROBUS0_NICERF)

/*
E28 module
AN  <-> Busy
INT <-> DIO1
PWM <-> DIO2
*/

#define NSS     NSS_0
#define DIO1    INT_0                               //DIO1 pin on LoRa device, used for RX and TX done 
#define RFBUSY  AN_0                                //busy line
#define NRESET  RESET_0                     //reset pin on LoRa device


#elif defined(MIKROBUS1_E28) || defined(MIKROBUS1_NICERF)

/* same mapping but on port 1*/

#define NSS     NSS_1
#define DIO1    INT_1
#define RFBUSY  AN_1
#define NRESET  RESET_1


/* ********************* */

#elif defined(MIKROBUS0_LAMBDA80)

/*
Lambda80C module
AN  <-> DIO1
INT <-> Busy
PWM <-> DIO2
*/

#define NSS     NSS_0
#define DIO1    AN_0                                //DIO1 pin on LoRa device, used for RX and TX done 
#define RFBUSY  INT_0                               //busy line
#define NRESET  RESET_0                     //reset pin on LoRa device


#elif defined(MIKROBUS1_LAMBDA80)

/* same mapping but on port 1*/

#define NSS     NSS_1
#define DIO1    AN_1
#define RFBUSY  INT_1
#define NRESET  RESET_1



#else

#error Unknown module

#endif


#define LED1 2                                  //on board LED, high for on

#define DIO2  -1                                //DIO2 pin on LoRa device, normally not used so set to -1 
#define DIO3 -1                                 //DIO3 pin on LoRa device, normally not used so set to -1
#define RX_EN -1                                //pin for RX enable, used on some SX128X devices, set to -1 if not used
#define TX_EN -1                                //pin for TX enable, used on some SX128X devices, set to -1 if not used 
#define BUZZER -1                               //pin for buzzer, set to -1 if not used 
#define VCCPOWER 14                             //pin controls power to external devices

#define LORA_DEVICE DEVICE_SX1280               //we need to define the device we are using

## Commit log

2021-06-25 Firts commit: PCB for ESP32 Vroom + 2 Mikrobus modules + 2 groves
2021-06-30 Commit board_V1 + Lib + README
    Readme a completer.
    [Board_ESP_MiKroBus_V1.kicad_pcb, Board_ESP_MiKroBus_V1.sch, SMA-J-P-H-ST-EM1.step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]
2021-07-01 Adding images
    MiKroBus_Module: Main folder
    Picture folder: Board_Tinysgs_2.4GHz_V1
2021-07-01 README Changes and rename Lib & Fp folder name
    Change of "Lib & empreinte" into "Lib & Fp" folder name
    README Changes
    [SMA-J-P-H-ST-EM1.step, U.FL-R-SMT_01_.step]
2021-07-09 Update README Board
    Update comming:
    Kicad board project
    Picture
    mikrobus E28 / Lambda80C board
2021-07-15 README + new picture
    Kicad project will come later
    + Lambda80 module
    + E28m odule
    Need more description about the pin and sofware
2021-07-19 Push board_V1 project
    [Board_ESP_MiKroBus_V1.kicad_pcb, Board_ESP_MiKroBus_V1.sch, Board_ESP_MikroBus_V1.kicad_pcb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]
2021-07-19 Adding Board_Tinysgs README
2021-07-19 E28 project
    [07-08_ carte_mikrobus_E28.kicad_pcb, 07-08_ carte_mikrobus_E28.sch, EDI2CAP.CFG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]
2021-07-19 Rename E28 project + picture
    [Board_mikrobus_E28.kicad_pcb, Board_mikrobus_E28.sch]
2021-07-19 Lambda80 mikrobus board project
    [Board_Mikrobus_Lambda80C.kicad_pcb, Board_Mikrobus_Lambda80C.sch, EDI2CAP.CFG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]
2021-07-23 add images of pcbs
2021-07-26 Update images Board_V1
2021-07-29 add refto grove boards
2021-09-17 add dir for Arduino sketches
2021-09-17 add images of ESP32-WROOM-32U-38pins
2021-12-14 add dirs for exported Gerber files
2021-12-14 add gerber files
2021-12-15 add battery
2021-12-22 add ref to power
2021-12-22 add ref to Adafruit Universal USB / DC / Solar Lithium Ion/Polymer charger - bq24074
2021-12-22 add ref to Solar Power Manager Micro
2021-12-22 add images of 250_2g4_ground_stations PCB
2022-01-27 add images for tinygs2g4 mount party @ IUT1 Grenoble
2022-03-24 add timer example
2022-03-28 add default board
2022-04-29 add olimex ESP32
2024-03-21 add contrib from Nicolas Nohlier
    [Board_mikrobus_Nice1280_TCXO.kicad_pcb, Board_mikrobus_Nice1280_TCXO.kicad_sch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]
2024-04-10 improve trace
2024-04-13 init ADC boards
2024-04-15 add frame collisions
2024-04-16 add syncword to receiver; change packet trace in receiver
2024-04-17 add module for Arduino_UNO_click_shield
2024-04-25 add antennas sections
2024-04-25 add sirio 2.4 Ghz antenna
2024-09-26 add short tuto for power monitoring
2025-04-07 fix pin
2025-04-07 add trace
2025-04-30 improve traces
2025-05-01 add CAD; add debug defines for RadioLib
2025-05-01 init CC1101 for ESP32
